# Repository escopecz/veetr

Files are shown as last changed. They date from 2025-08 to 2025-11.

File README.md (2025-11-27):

# Veetr

Veetr provides open source software and hardware for tracking wind speed, direction, speed over ground, GPS tracking, heading, heel and other data in real time during a sail. Great fit for day-sailers or weekend-sailers.

## Features

### 🌊 Real-time Sailing Data
- **SOG** (Speed Over Ground) using GPS
- **AWS** (Apparent Wind Speed) using ultrasonic wind sensor
- **AWA** (Apparent Wind Angle) using ultrasonic wind sensor  
- **TWS** (True Wind Speed) calculated from SOG, AWS, and AWA
- **TWA** (True Wind Angle) calculated from SOG and AWA
- **Heel** (Heeling angle) using 9-axis IMU sensor
- **HDG** (Heading angle to magnetic north) using 9-axis IMU sensor
- **GPS Position** with satellite count and HDOP accuracy

### 📱 Progressive Web App (PWA)
- **Offline Capability** - Works without internet connection after initial load
- **Mobile Installation** - Install as native app on phones and tablets
- **Responsive Design** - Optimized for all screen sizes and orientations
- **Light & Dark Mode** - Perfect for sunny days and night passages
- **Always Up-to-Date** - Automatic updates when internet is available

### 🔄 Firmware & Connectivity
- **OTA Updates** - Over-the-air firmware updates through the web app
- **Multi-Device Support** - Up to 4 devices can connect simultaneously
- **Bluetooth Security** - Discovery mode only when button is pressed (5-minute window)
- **Real-time Data** - 1-second refresh rate for live sailing data
- **RSSI Monitoring** - Signal strength indicator with connection quality

### 🏁 Racing Features
- **Regatta Starting Line** - Pin 2 GPS points and track distance to start line
- **Visual Compass** - Wind direction and heading display with smooth animations
- **Satellite Status** - GPS quality monitoring with visual indicators
- **Connection Management** - Robust BLE connection with automatic reconnection

## Why Veetr?

### 💰 Cost-Effective
- **Open source software** - Free firmware and app to use, install, host yourself and/or modify
- **Open hardware** - PCB Gerber files included for custom manufacturing ([download files](./pcb/))
- **Modular design** - Use standard sensors from AliExpress with pin headers ([full parts list](./docs/HARDWARE.md))
- **3D printed case** - Print yourself or with local maker community
- **Budget-friendly** - Complete electronic components for ~$250 (2025 pricing)

### ⚡ Performance & Reliability
- **Modular architecture** - Easy to repair, upgrade, or replace individual sensors
- **Low power consumption** - 10Ah powerbank provides ~24 hours at 1-second refresh rate
- **No moving parts** - Ultrasonic wind sensor for precision and durability
- **Lightweight** - Wind sensor: 66x64mm, 89 grams
- **Quality sensors** - High-precision components without compromise

### 🔒 Security & Independence
- **Physical Security** - Bluetooth discoverable only with button press (5-minute window)
- **Privacy-First** - All data stays on your device, no cloud dependency
- **USB-C Power** - Works with any standard powerbank or USB-C charger

## Technology Stack

### 🌐 Web Dashboard:
- **React 18** + TypeScript + Vite for modern development
- **Progressive Web App (PWA)** with Service Worker for offline capability
- **Web Bluetooth API** for direct BLE communication
- **Lucide React Icons** for consistent, scalable vector graphics
- **CSS Custom Properties** for theming and responsive design
- **Responsive Layout** optimized for mobile, tablet, and desktop

### 🔧 ESP32 Firmware:
- **Arduino Framework** via PlatformIO for robust development
- **NimBLE Stack** for Bluetooth Low Energy with multi-connection support
- **Multi-Sensor Integration** ([hardware details](./docs/HARDWARE.md)):
  - GPS module (UART) for position and speed
  - BNO080 IMU (I2C) for heading and heel
  - Ultrasonic wind sensor (RS485) for wind speed/direction
- **RSSI Filtering** with moving average for stable signal strength
- **Discovery Mode Security** with button-activated pairing
- **OTA Update Support** for seamless firmware upgrades

### 📡 Communication Protocol:
- **BLE GATT Services** for sensor data streaming
- **JSON Data Format** for structured sensor readings
- **Real-time Updates** at 1Hz refresh rate
- **Multi-device Broadcasting** supporting up to 4 concurrent connections

## 🔧 Hardware Design

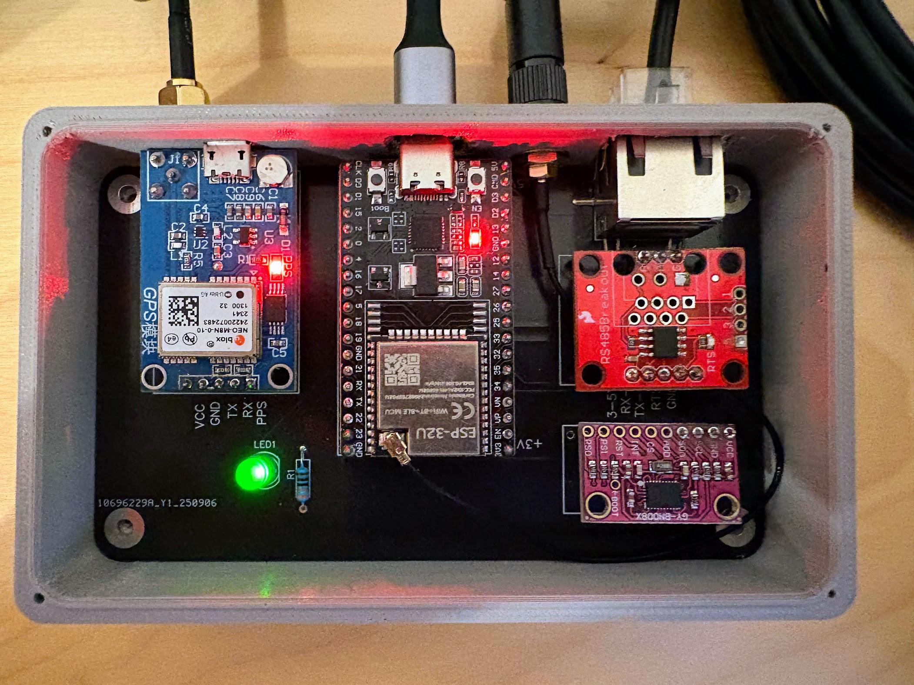
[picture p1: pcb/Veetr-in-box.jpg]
Veetr PCB Assembly


Veetr uses a **modular breakout board design** with standard off-the-shelf sensors for maximum flexibility and repairability.

**📋 Full Details**: [Hardware Guide](./docs/HARDWARE.md) | **🔧 PCB Files**: [Manufacturing Files](./pcb/)

## 🚀 Quick Start

### For Sailors (Using the App):
1. **Visit** [app.veetr.org](https://app.veetr.org) on your mobile device
2. **Install** the app (tap "Add to Home Screen" or "Install" prompt)
3. **Press** the physical button on your Veetr device to enable discovery mode or restart the device
4. **Connect** via the Bluetooth button in the app
5. **Sail** with real-time data - works offline once connected!

### For Developers:
```bash
# Clone and setup web app
git clone https://github.com/escopecz/veetr.git
cd veetr/app
npm install
npm run dev

# Setup firmware development
cd ../firmware
pio run --target upload
```

## Documentation

For detailed information, see the [docs/](./docs/) directory:

- **[Setup Guide](./docs/SETUP.md)** - Step-by-step user setup for sailors
- **[Development Guide](./docs/DEVELOPMENT.md)** - Developer workflow and contribution guide
- **[Hardware Guide](./docs/HARDWARE.md)** - ESP32 wiring and sensor specifications
- **[PCB Files](./pcb/README.md)** - Gerber files and PCB manufacturing information ([download Gerbers](./pcb/gerbers/))
- **[Compliance & Certifications](./docs/COMPLIANCE.md)** - FCC, CE, IC regulatory compliance
- **[Firmware Update Guide](./docs/FIRMWARE_UPDATE.md)** - How to update ESP32 firmware
- **[PlatformIO Guide](./docs/PLATFORMIO.md)** - Firmware development details
- **[Storage Architecture](./docs/STORAGE.md)** - Data storage and persistence
- **[Version Management](./docs/VERSION_MANAGEMENT.md)** - Release and versioning workflow

## License

MIT License - see [LICENSE](./LICENSE) for details.

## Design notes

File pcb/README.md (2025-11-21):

# Veetr PCB Files

This directory contains the PCB design files for the Veetr ESP32 breakout board.

Veetr PCB Assembly

## Modular Design Philosophy

Veetr uses a **modular breakout board design** with standard off-the-shelf sensors for maximum flexibility and repairability.

**📋 Full Details**: [Hardware Guide](../docs/HARDWARE.md)

## Design Files

The complete PCB and schematic design is available on EasyEDA (OSHWLab):

**🔗 [Veetr Breakout Board on EasyEDA](https://oshwlab.com/linhartescope/esp32-breakout-board)**

This project includes:
- Complete schematic design
- PCB layout with component placement
- Bill of Materials (BOM)
- 3D preview of the assembled board

The design can be opened, edited, and customized directly in EasyEDA's web-based editor. You can also fork the project to create your own variations. **Contributions and improvements are welcome!**

## Manufacturing Files

### Gerber Files (`gerbers/`)
Generated on: 2025-09-06

Contains standard Gerber files for PCB fabrication:
- `Gerber_TopLayer.GTL` - Top copper layer
- `Gerber_BottomLayer.GBL` - Bottom copper layer  
- `Gerber_TopSilkscreenLayer.GTO` - Top silkscreen
- `Gerber_BottomSilkscreenLayer.GBO` - Bottom silkscreen
- `Gerber_TopSolderMaskLayer.GTS` - Top solder mask
- `Gerber_BottomSolderMaskLayer.GBS` - Bottom solder mask
- `Gerber_BoardOutlineLayer.GKO` - Board outline
- `Gerber_DocumentLayer.GDL` - Documentation layer
- `Drill_PTH_Through.DRL` - Plated through holes
- `Drill_PTH_Through_Via.DRL` - Via holes
- `Drill_NPTH_Through.DRL` - Non-plated through holes

## PCB Specifications

- **Board Size**: TBD
- **Layers**: 2-layer PCB
- **Thickness**: 1.6mm (standard)
- **Material**: FR4
- **Finish**: HASL (Hot Air Solder Leveling) or ENIG
- **Min Trace Width**: 0.1mm
- **Min Via Size**: 0.2mm

## Manufacturing Notes

See https://docs.easyeda.com/en/PCB/Order-PCB for specific ordering instructions and requirements.

### Recommended PCB Manufacturers
- **JLCPCB** - Cost-effective for prototypes and small runs
- **PCBWay** - Good quality and service
- **OSH Park** - USA-based, high quality
- **AISLER** - Europe-based

## License

This PCB design is released under the same MIT license as the rest of the Veetr project.

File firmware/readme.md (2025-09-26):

# Veetr Sailing Dashboard

A sailing vessel monitoring system built with ESP32, providing real-time data on vessel speed, wind conditions, and tilt angle through a modern web application that connects via Bluetooth Low Energy (BLE).

## 🚨 Architecture Update

**This project has been migrated from WiFi Access Point to BLE (Bluetooth Low Energy) connectivity:**

- **OLD:** ESP32 hosted WiFi Access Point + WebSocket server + web files on SPIFFS
- **NEW:** ESP32 BLE server + externally hosted web app + Web Bluetooth API connection

**Key Changes:**
- Web application is now hosted externally (GitHub Pages, Netlify, etc.) over HTTPS
- ESP32 no longer needs to host web files or run a WiFi Access Point
- Connection is via Bluetooth Low Energy using Web Bluetooth API with NimBLE-Arduino
- Significantly reduced memory usage and improved power efficiency
- Browser support limited to Chrome, Edge, Opera (no Safari/iOS support)
- Standardized JSON API with marine terminology (SOG, AWS, TWS, etc.)
- Robust sensor error handling - system continues to operate even if sensors fail

## Features

- Real-time monitoring of sailing data:
  - Vessel speed over ground (SOG) via GPS with noise filtering
  - Wind speed and angle (AWS/AWA) via ultrasonic sensor
  - Calculated true wind speed and angle (TWS/TWA) using vessel motion
  - Vessel heel/tilt angle via BNO080 IMU sensor (when available)
  - GPS position and satellite information
  - BLE connection strength (RSSI)
- Progressive Web App (PWA) dashboard:
  - Installable on mobile devices
  - Works offline (interface only)
  - Responsive design for all screen sizes
  - Hosted externally (GitHub Pages or any HTTPS hosting)
- Bluetooth Low Energy (BLE) connectivity:
  - Direct connection between web app and ESP32
  - No WiFi network required
  - Low power consumption
  - Secure pairing
  - Multi-client support
- Real-time data updates via BLE notifications (1Hz)
- Data visualization with gauges and charts
- Robust sensor error handling - system continues operating even if sensors fail

## BLE JSON API

The Veetr Sailing Dashboard transmits data via BLE notifications using a standardized JSON format with marine terminology. Data is sent approximately every 1 second to all connected BLE clients.

### BLE Service and Characteristics

- **Service UUID:** `12345678-1234-5678-9abc-def123456789`
- **Characteristic UUID:** `87654321-4321-8765-cba9-fedcba987654`
- **Properties:** Read, Notify
- **Data Format:** JSON string encoded as UTF-8

### JSON Data Structure

```json
{
  "SOG": 4.2,
  "COG": 185.5,
  "lat": 37.7749,
  "lon": -122.4194,
  "satellites": 8,
  "hdop": 1.2,
  "AWS": 12.5,
  "AWA": 45.5,
  "TWS": 10.8,
  "TWA": 52.3,
  "heel": -5.2,
  "HDM": 185.5,
  "accelX": 0.12,
  "accelY": -0.05,
  "accelZ": 9.81,
  "rssi": -65,
  "deviceName": "Luna_Port_Side"
}
```

### Field Definitions

| Field | Type | Unit | Description | Marine Standard |
|---|---|---|---|---|
| `SOG` | float | knots | Speed Over Ground from GPS | ✓ |
| `COG` | float | degrees | Course Over Ground from GPS (0-360°) | ✓ |
| `lat` | float | decimal degrees | GPS Latitude (WGS84) | ✓ |
| `lon` | float | decimal degrees | GPS Longitude (WGS84) | ✓ |
| `satellites` | integer | count | Number of GPS satellites in use | ✓ |
| `hdop` | float | dimensionless | Horizontal Dilution of Precision | ✓ |
| `AWS` | float | knots | Apparent Wind Speed | ✓ |
| `AWA` | float | degrees | Apparent Wind Angle (0-360°) relative to bow | ✓ |
| `TWS` | float | knots | True Wind Speed (calculated) | ✓ |
| `TWA` | float | degrees | True Wind Angle (0-360°) relative to bow | ✓ |
| `heel` | float | degrees | Vessel heel angle (+ = starboard, - = port) | ✓ |
| `HDM` | float | degrees | Heading Magnetic from magnetometer (0-360°) | ✓ |
| `accelX` | float | m/s² | Acceleration along X-axis (fore/aft) | ✓ |
| `accelY` | float | m/s² | Acceleration along Y-axis (port/starboard) | ✓ |
| `accelZ` | float | m/s² | Acceleration along Z-axis (up/down) | ✓ |
| `rssi` | integer | dBm | BLE signal strength (more negative = weaker) | - |
| `deviceName` | string | - | BLE device name for multi-device identification | - |

### Field Behavior

**Always Present:**
- `SOG`, `COG`, `lat`, `lon`, `satellites`, `hdop` - GPS data (0 values if no GPS fix)
- `rssi` - BLE signal strength
- `deviceName` - BLE device name for multi-device identification

**Conditionally Present:**
- `AWS` - Only present if wind sensor is connected and working
- `AWA` - Only present if wind sensor is connected and working
- `TWS` - Only present if wind sensor and GPS are working (calculated from AWS, AWA, SOG)
- `TWA` - Only present if wind sensor and GPS are working (calculated from AWA, SOG)  
- `heel` - Only present if BNO080 IMU sensor is detected and working
- `HDM` - Only present if BNO080 magnetometer is working and has valid data
- `accelX`, `accelY`, `accelZ` - Only present if BNO080 accelerometer is working and has valid data

### GPS Speed Filtering

The system includes intelligent GPS speed filtering that combines GPS track analysis with accelerometer data to accurately distinguish real vessel movement from GPS noise when stationary or docked.

**How it works:**
1. **GPS Track Analysis:** Collects recent GPS positions and analyzes the vessel's track for distance traveled and bearing changes
2. **Accelerometer Movement Detection:** Analyzes acceleration magnitude variations to detect physical movement independent of GPS
3. **Sensor Fusion:** Combines both GPS and accelerometer data for more accurate movement detection
4. **Quality Check:** Only uses GPS data with ≥4 satellites and HDOP ≤ 3.0
5. **Adaptive Thresholds:** Adjusts noise filtering thresholds based on sensor confidence
6. **Hysteresis:** Different thresholds prevent speed "flickering" between 0 and low values

**Key Features:**
- **Dual-Sensor Validation:** Uses both GPS track analysis and accelerometer data when IMU is available
- **Independent Movement Detection:** Accelerometer provides movement confirmation independent of GPS signal quality
- **Adaptive Filtering:** Lower thresholds when both sensors confirm movement, higher when stationary
- **Graceful Degradation:** Falls back to GPS-only filtering when IMU sensor is not available
- **Responsive:** Quickly detects when vessel starts moving after being stationary

**Enhanced Thresholds (with Accelerometer):**
- **High Confidence Movement:** 0.05 knots (both GPS and accelerometer detect movement)
- **Normal Filtering:** 0.08 knots (mixed signals or IMU unavailable)
- **High Confidence Stationary:** 0.12 knots (both sensors confirm stationary state)
- **Start Moving Hysteresis:** +0.1 knots above respective threshold

**Accelerometer Movement Detection:**
- **Acceleration Variance:** Detects changes in acceleration magnitude indicating movement
- **Magnitude Analysis:** Monitors total acceleration range and standard deviation
- **Validation:** Ensures accelerometer readings are reasonable (gravity present: 8-12 m/s²)
- **Noise Immunity:** Filters false positives from sensor noise or vibrations

**Why This Approach:**
This dual-sensor approach significantly improves accuracy over GPS-only filtering:
- **Eliminates False Positives:** GPS noise won't register as movement without accelerometer confirmation
- **Reduces False Negatives:** Real movement detected by accelerometer even with poor GPS signal
- **Better Sensitivity:** Can detect very slow movement (below GPS noise floor) when accelerometer confirms motion
- **Marine Environment Optimized:** Accounts for wave motion, anchoring, and low-speed maneuvering scenarios

### Error Handling

The system is designed to be robust against sensor failures:

- **Missing GPS:** System continues to operate, GPS fields show default values
- **Missing Wind Sensor:** Wind fields (`AWS`, `AWA`, `TWS`, `TWA`) are omitted from JSON
- **Missing IMU Sensor:** Heel field is omitted from JSON
- **Sensor Failures:** Individual sensor failures don't affect other sensors or BLE transmission
- **BLE Reliability:** JSON is transmitted every 1 second regardless of sensor status

### BLE Commands

The Veetr Sailing Dashboard supports bidirectional communication via a dedicated command characteristic. This allows web applications to configure device settings and trigger actions remotely.

#### Command Characteristic

- **Characteristic UUID:** `11111111-2222-3333-4444-555555555555`
- **Properties:** Write
- **Data Format:** JSON string encoded as UTF-8

#### Available Commands

**1. Reset Heel Angle (Calibration)**
```json
{
  "action": "resetHeelAngle"
}
```
Calibrates the heel angle sensor by setting the current tilt as the new zero point. Useful for adjusting when the boat is level.

**2. Set Device Name**
```json
{
  "action": "setDeviceName",
  "deviceName": "Luna_Port_Side"
}
```
Sets the BLE device name used for Bluetooth discovery. This is essential for distinguishing between multiple ESP32 devices. Limited to 1-20 characters, alphanumeric, underscore, hyphen, and space only.

**3. Regatta Line Markers (Future)**
```json
{
  "action": "regattaSetPort"
}
```
```json
{
  "action": "regattaSetStarboard"
}
```
Placeholder commands for future regatta timing functionality.

#### Multi-Device Management

The device name feature is particularly useful for sailing applications with multiple sensors:

- **Fleet Management:** "Veetr_01", "Veetr_02", "Veetr_03"
- **Multi-Hull Boats:** "Veetr_Port", "Veetr_Starboard"
- **Multiple Locations:** "Veetr_Mast", "Veetr_Cockpit"
- **Development/Testing:** "Veetr_Dev", "Veetr_Prod"

When you change the device name, the ESP32 immediately restarts its BLE advertising with the new name, making it instantly discoverable under the new identifier.

### Example Client Code (JavaScript)

```javascript
// Connect to Veetr Sailing BLE device
const device = await navigator.bluetooth.requestDevice({
  filters: [{ name: 'Veetr_Sailing' }],
  optionalServices: ['12345678-1234-5678-9abc-def123456789']
});

const server = await device.gatt.connect();
const service = await server.getPrimaryService('12345678-1234-5678-9abc-def123456789');

// Get sensor data characteristic for reading
const sensorCharacteristic = await service.getCharacteristic('87654321-4321-8765-cba9-fedcba987654');

// Get command characteristic for writing
const commandCharacteristic = await service.getCharacteristic('11111111-2222-3333-4444-555555555555');

// Listen for sensor data notifications
sensorCharacteristic.addEventListener('characteristicvaluechanged', (event) => {
  const value = event.target.value;
  const jsonString = new TextDecoder().decode(value);
  const data = JSON.parse(jsonString);
  
  console.log('Speed:', data.SOG, 'knots');
  console.log('Wind Speed:', data.AWS, 'knots');
  console.log('Heel:', data.heel, 'degrees');
  console.log('Device:', data.deviceName);
  
  // New BNO080 sensor data (if available)
  if (data.HDM !== undefined) {
    console.log('Magnetic Heading:', data.HDM, 'degrees');
  }
  
  if (data.accelX !== undefined) {
    console.log('Acceleration:', {
      x: data.accelX,
      y: data.accelY, 
      z: data.accelZ
    }, 'm/s²');
  }
});

await sensorCharacteristic.startNotifications();

// Send commands to the device
async function setDeviceName(newName) {
  const command = {
    action: "setDeviceName",
    deviceName: newName
  };
  
  const encoder = new TextEncoder();
  const data = encoder.encode(JSON.stringify(command));
  await commandCharacteristic.writeValue(data);
  
  console.log(`Device name set to: ${newName}`);
}

async function resetHeelAngle() {
  const command = { action: "resetHeelAngle" };
  
  const encoder = new TextEncoder();
  const data = encoder.encode(JSON.stringify(command));
  await commandCharacteristic.writeValue(data);
  
  console.log('Heel angle reset (calibrated)');
}

// Example usage
await setDeviceName('Luna_Port_Side');
await resetHeelAngle();
```

## Hardware Components

- ESP32 DevKitC WROOM-32U (main controller with external antenna)
- NEO-7M GPS Module with external antenna
- Ultrasonic Wind Speed and Direction Sensor (RS485) - **Auto-detects sensor format**
- GY-BNO080 9-Axis IMU Sensor (I2C)
- RS485 to UART Converter Module

### Wind Sensor Compatibility

The system automatically detects and supports two different ultrasonic wind sensor formats:

- **IEEE754 Format**: 9600 baud, 8E1, registers 0x0001, IEEE 754 float encoding
- **Integer Format**: 4800 baud, 8N1, registers 0x0000, integer×100 encoding

Auto-detection occurs at startup by attempting communication with each format and validating the response data. Once detected, the system locks to the working format for optimal performance.

## Getting Started

### Development Setup

For complete development environment setup, daily workflow, and contribution guidelines, see the **[Development Guide](../docs/DEVELOPMENT.md)**.

This firmware documentation focuses on ESP32-specific implementation details and BLE protocol specifications.

#### Hardware Setup

1. **Wire the Sensors to ESP32**
For detailed hardware wiring and sensor specifications, see the **[Hardware Guide](../docs/HARDWARE.md)**.

1. **Wire the Sensors to ESP32**
   - **GPS Module**: UART connection (GPIO16/17)
   - **BNO080 IMU**: I2C connection (GPIO21/22)  
   - **Wind Sensor**: RS485 connection (GPIO32/33/14)

2. **Connect ESP32 to Computer**
   - Use USB cable for programming and power during development
   - For deployment: 5V power bank (portable) or boat's 12V supply with voltage regulator

#### Software Installation

For complete software setup, see the **[Development Guide](../docs/DEVELOPMENT.md)**.

1. **Clone this repository**
   ```bash
   git clone https://github.com/yourusername/luna.git
   cd luna
   ```
   
   Alternatively, download the ZIP file from GitHub and extract it.

2. **Open the project in VS Code with PlatformIO**
   - Launch VS Code
   - Go to Extensions (Ctrl+Shift+X or Cmd+Shift+X)
   - Search for and install "PlatformIO IDE"
   - Restart VS Code when prompted
   - Open the Luna project folder (File > Open Folder)
   - Wait for PlatformIO to initialize the project (this may take a few minutes)

3. **Install required libraries**
   PlatformIO should automatically install the required libraries based on the `platformio.ini` file. If not, you can install them manually:
   
   - Through PlatformIO Home:
     - Click on the PlatformIO icon in the sidebar
     - Go to "Libraries" and search for each library:
       - ArduinoJson
       - SparkFun BNO080 Cortex Based IMU
       - TinyGPS++
       - ModbusMaster
     - Click "Add to Project" and select your project
   
   - Or through the CLI:
     ```bash
     pio pkg install --library "bblanchon/ArduinoJson"
     pio pkg install --library "sparkfun/SparkFun BNO080 Cortex Based IMU"
     pio pkg install --library "mikalhart/TinyGPSPlus"
     pio pkg install --library "4-20ma/ModbusMaster"
     ```

For build, upload, and testing procedures, see the **[Development Guide](../docs/DEVELOPMENT.md)**.

### Connecting to the Dashboard

#### Web Application Access

The Veetr Sailing Dashboard web application is hosted externally (not on the ESP32) to provide better performance and reliability. You can access it at:

**Live Dashboard:** [https://yourusername.github.io/luna-dashboard](https://yourusername.github.io/luna-dashboard)

*Note: Replace the URL above with your actual hosted dashboard URL*

#### Connecting via Bluetooth Low Energy (BLE)

1. **Power on the ESP32**
   - If using USB: Connect to a computer or power bank
   - If using external power: Connect to the boat's power supply

2. **Wait for system initialization**
   - The ESP32 needs about 10-15 seconds to boot up and start the BLE server
   - The ESP32 will advertise as "Luna_Sailing" and be discoverable by BLE devices

3. **Access the web dashboard**
   - Open a BLE-compatible browser (Chrome, Edge, or Opera on desktop/Android)
   - Navigate to the dashboard URL (hosted externally)
   - The dashboard must be served over HTTPS for Web Bluetooth API to work

4. **Connect to the ESP32**
   - Click the "Connect to Luna Sailing" button in the dashboard
   - Your browser will show a device selection dialog
   - Select "Luna_Sailing" from the list of available devices
   - Click "Pair" or "Connect"
   - The connection status will change to "Connected via BLE"

5. **Verify the connection**
   - Once connected, you should see real-time data updating in the dashboard
   - Check that the data is updating (approximately once per second)
   - Satellite count should be visible if GPS is connected
   - Sensor values should respond to actual changes in movement, wind, etc.

#### Browser Compatibility

**Supported Browsers with Web Bluetooth API:**
- **Chrome** (Desktop: Windows, macOS, Linux; Mobile: Android)
- **Edge** (Desktop: Windows, macOS; Mobile: Android)
- **Opera** (Desktop: Windows, macOS, Linux; Mobile: Android)

**Not Supported:**
- Safari (iOS/macOS) - Does not support Web Bluetooth API
- Firefox - Limited or no Web Bluetooth support
- Most iOS browsers - iOS restricts Web Bluetooth API

**Recommended Setup:**
- Android device with Chrome browser
- Windows/macOS/Linux desktop with Chrome or Edge
- Ensure the dashboard is served over HTTPS

#### Troubleshooting Connection Issues

- **Can't find the Luna_Sailing BLE device**
  - Make sure the ESP32 is powered on and fully booted (wait 15-20 seconds)
  - Try restarting the ESP32 by pressing the reset button
  - Move closer to the ESP32 - BLE range is typically 10-30 meters in open space
  - Ensure you're using a supported browser (Chrome, Edge, or Opera)
  - Check that Bluetooth is enabled on your device

- **Browser shows "Bluetooth not supported" error**
  - Make sure you're using Chrome, Edge, or Opera (not Safari or Firefox)
  - Ensure the dashboard is served over HTTPS (required for Web Bluetooth API)
  - Try updating your browser to the latest version
  - On Android, ensure location services are enabled (required for BLE scanning)

- **Dashboard loads but BLE connection fails**
  - Check that your device's Bluetooth is turned on
  - Try clearing your browser cache and cookies
  - Restart your browser completely
  - Try connecting from a different device
  - Check the browser console (F12) for error messages

- **Connected but no data appears**
  - Check the BLE connection status indicator in the dashboard
  - Refresh the page and try reconnecting
  - If using real sensors, verify they are properly connected to the ESP32
  - Check the ESP32 serial monitor output for any error messages
  - Try restarting the ESP32

- **iOS/Safari compatibility issues**
  - Unfortunately, iOS Safari does not support Web Bluetooth API
  - Use an Android device or desktop browser instead
  - Consider using a third-party iOS browser that might support Web Bluetooth (limited options)

- **Data updates are slow or intermittent**
  - This may be due to BLE connection quality or interference
  - Move closer to the ESP32
  - Remove sources of 2.4GHz interference (WiFi, microwaves, etc.)
  - Try restarting both the ESP32 and reconnecting from the browser

### Installing as a PWA

The Luna Sailing Dashboard is designed as a Progressive Web App (PWA), which means you can install it on your device for easier access and a more app-like experience. Once installed, you can launch it directly from your home screen without opening a browser and navigating to the URL.

**Important:** The PWA must be served over HTTPS to enable installation and Web Bluetooth API functionality.

#### On iPhone/iPad (Safari)

**Note:** While you can install the PWA on iOS, Web Bluetooth is not supported in Safari, so you'll need to use an Android device or desktop browser for BLE connectivity.

1. Open the dashboard URL in Safari (the externally hosted HTTPS version)
2. Tap the Share button (rectangle with an arrow pointing up) at the bottom of the screen
3. Scroll down and tap "Add to Home Screen"
4. You can rename the app if you wish
5. Tap "Add" in the top-right corner
6. The Luna app icon will appear on your home screen
7. Tap the icon to launch the app in full-screen mode

#### On Android (Chrome)

1. Open the dashboard in Chrome (navigate to your hosted dashboard URL)
2. Tap the three-dot menu button in the top-right corner
3. Select "Add to Home screen" or "Install app" (the wording may vary)
4. If prompted, confirm by tapping "Add" or "Install"
5. The Luna app icon will appear on your home screen
6. Tap the icon to launch the app in full-screen mode

#### On Windows (Chrome/Edge)

1. Open the dashboard in Chrome or Edge (navigate to your hosted dashboard URL)
2. Look for the install icon in the address bar (a computer with a down arrow) or the three-dot menu
3. Click "Install Luna Sailing" or "Install app"
4. Confirm by clicking "Install" in the popup
5. The app will install and can be launched from the Start menu or desktop
6. You can also pin it to the taskbar for quick access

#### On macOS (Chrome)

1. Open the dashboard in Chrome (navigate to your hosted dashboard URL)
2. Click the three-dot menu in the top-right corner
3. Select "Install Luna Sailing..." or "Create shortcut..."
4. Choose whether to open as a window or tab
5. Click "Install" or "Create"
6. The app will be added to your Applications folder and can be launched from there

#### Benefits of Installing as a PWA

- **Easier Access**: Launch directly from your home screen without typing the URL
- **Full-Screen Experience**: No browser interface elements taking up space
- **Offline Interface**: The basic dashboard UI remains accessible even without connection (though live data requires BLE connection)
- **Automatic Reconnection**: The app will attempt to reconnect to the ESP32 when BLE connection is available
- **Better Performance**: Installed PWAs often have better performance than browser tabs

#### Troubleshooting PWA Installation

- **Install option not appearing**:
  - Make sure you've fully loaded the dashboard page
  - Try refreshing the page
  - Some browsers may require you to visit the site more than once before offering installation
  - Ensure the site is served over HTTPS
  
- **App not working after installation**:
  - Make sure the ESP32 is powered on and BLE is advertising
  - Try connecting to the ESP32 via BLE from the installed app
  - Check that Bluetooth is enabled on your device
  
- **App showing offline mode**:
  - This is normal if you're not connected to the ESP32 via BLE
  - The app interface remains available, but live data requires BLE connection
  - Connect to the ESP32 via BLE to start receiving data

### BLE Connection and Pairing

The Luna Sailing Dashboard uses Bluetooth Low Energy (BLE) for communication between the ESP32 and client devices. The system is designed to be robust and supports multiple simultaneous connections.

#### BLE Service Information

- **Device Name:** `Luna_Sailing`
- **Service UUID:** `12345678-1234-5678-9abc-def123456789`
- **Characteristic UUID:** `87654321-4321-8765-cba9-fedcba987654`
- **Data Rate:** ~1 Hz (every 1000ms)
- **Data Format:** JSON string with marine terminology

#### Initial Connection Process

1. **Power on the ESP32**
   - Connect to power source (USB or external power)
   - Wait 10-15 seconds for full system initialization
   - The ESP32 will start advertising as "Luna_Sailing"

2. **Activate Discovery Mode**
   - Press and hold the BOOT button (GPIO0) for 1+ seconds
   - The built-in LED (GPIO2) will turn on to indicate discovery mode is active
   - Device becomes discoverable to nearby BLE clients for 5 minutes
   - Range: typically 10-30 meters in open space

3. **Connect from Client Device**
   - Use a BLE-compatible browser or application
   - Search for "Luna_Sailing" in available BLE devices
   - Select device and confirm pairing
   - **Note**: Discovery mode expires after 5 minutes for security
   - Connection establishment takes 2-5 seconds

#### Sensor Initialization Status

The system performs sensor detection during startup:

- **GPS Module:** Always initialized (may take 30-90 seconds for first satellite fix)
- **Wind Sensor:** Automatically detected via RS485 communication
- **IMU Sensor:** Detected via I2C bus scan at startup
- **Missing Sensors:** System continues operation with available sensors only

#### Data Transmission

Once connected, the ESP32 automatically sends JSON data every 1 second:

- **Reliable Timing:** 1Hz transmission regardless of sensor status
- **Error Resilience:** Failed sensors don't interrupt data flow
- **Multi-Client:** Supports multiple simultaneous BLE connections
- **Low Latency:** Minimal delay between sensor reading and transmission

#### BLE Connection Management

**Automatic Reconnection:**
- Client applications should implement automatic reconnection
- ESP32 continues advertising after disconnections
- Previous pairing information is remembered

**Connection Stability:**
- Move closer to ESP32 if connection is unstable
- Avoid obstacles and interference sources
- Battery level affects BLE transmission power

**Multi-Device Support:**
- Multiple phones/tablets can connect simultaneously
- Each client receives independent data stream
- No limit on number of concurrent connections (within BLE stack limits)

#### BLE Discovery Security Mode

For enhanced security when deployed on boats, the ESP32 implements a button-activated discovery mode:

**Default Behavior:**
- BLE advertising is automatically disabled after 5 minutes of operation
- Device becomes "invisible" to BLE scanners for security
- Ideal for unattended deployment on boats in marinas or at anchor

**Manual Discovery Activation:**
- Press and hold the BOOT button (GPIO0) for 1+ seconds
- Built-in LED (GPIO2) turns on to confirm discovery mode is active
- BLE advertising enabled for exactly 5 minutes
- Press BOOT button again to deactivate early if needed

**Security Benefits:**
- Prevents unauthorized BLE scanning when device is unattended
- Perfect for marine environments where device may be left alone for hours/days
- Only advertises when intentionally activated by user
- Visual LED confirmation prevents accidental activation

### BLE Troubleshooting

#### Common BLE Connection Issues

- **Can't find the Luna_Sailing BLE device**
  - **First**: Press and hold the BOOT button (GPIO0) for 1+ seconds to activate discovery mode
  - Verify the built-in LED (GPIO2) turns on (discovery mode active)
  - Make sure the ESP32 is powered on and fully booted (wait 15-20 seconds)
  - Try restarting the ESP32 by pressing the reset button
  - Move closer to the ESP32 - BLE range is typically 10-30 meters in open space
  - Ensure you're using a supported browser (Chrome, Edge, or Opera)
  - Check that Bluetooth is enabled on your device
  - **Remember**: Discovery mode expires after 5 minutes - press BOOT button again if needed

- **Browser shows "Bluetooth not supported" error**
  - Make sure you're using Chrome, Edge, or Opera (not Safari or Firefox)
  - Ensure the dashboard is served over HTTPS (required for Web Bluetooth API)
  - Try updating your browser to the latest version
  - On Android, ensure location services are enabled (required for BLE scanning)

- **Dashboard loads but BLE connection fails**
  - Check that your device's Bluetooth is turned on
  - Try clearing your browser cache and cookies
  - Restart your browser completely
  - Try connecting from a different device
  - Check the browser console (F12) for error messages

- **Connected but no data appears**
  - Check the BLE connection status indicator in the dashboard
  - Refresh the page and try reconnecting
  - If using real sensors, verify they are properly connected to the ESP32
  - Check the ESP32 serial monitor output for any error messages
  - Try restarting the ESP32

- **iOS/Safari compatibility issues**
  - Unfortunately, iOS Safari does not support Web Bluetooth API
  - Use an Android device or desktop browser instead
  - Consider using a third-party iOS browser that might support Web Bluetooth (limited options)

- **Data updates are slow or intermittent**
  - This may be due to BLE connection quality or interference
  - Move closer to the ESP32
  - Remove sources of 2.4GHz interference (WiFi, microwaves, etc.)
  - Try restarting both the ESP32 and reconnecting from the browser

#### Sensor-Specific Troubleshooting

- **GPS shows no satellites or zero speed**
  - Ensure GPS antenna has clear view of sky
  - Move away from buildings, trees, or other obstructions
  - GPS requires 30-90 seconds for initial satellite acquisition
  - Check that GPS module is properly connected to pins 16/17

- **Wind data not appearing in JSON**
  - Verify wind sensor is connected to RS485 converter
  - Check RS485 converter connections to ESP32 pins 32/33
  - Ensure wind sensor has proper power supply (5-12V, 5V power bank works)
  - Check serial console for auto-detection messages during startup
  - System automatically tries both IEEE754 and integer formats
  - Wind sensor data only appears in JSON when sensor is detected and working
  - If auto-detection fails, verify Modbus address is set to 1 on the sensor

- **Heel angle not appearing in JSON**
  - Verify BNO080 IMU sensor is connected to I2C pins 21/22
  - Check that IMU sensor has proper power supply (3.3V)
  - Heel data only appears in JSON when IMU sensor is detected at startup
  - If IMU sensor fails after startup, heel data will stop appearing

- **JSON missing expected fields**
  - This is normal behavior - fields are omitted if sensors are not available
  - Only GPS fields (SOG, COG, lat, lon, satellites, hdop) and RSSI are always present
  - Wind fields (AWS, AWD) only appear when wind sensor is connected
  - Heel field only appears when IMU sensor is detected and working

## Development

### Sensor Calibration and Configuration

#### GPS Module (NEO-7M)

1. **Initial Setup**
   - The GPS module requires a clear view of the sky to acquire a satellite fix
   - For best results, position the antenna horizontally with an unobstructed view
   - Initial satellite acquisition can take 30-90 seconds in ideal conditions, or longer in poor conditions
   - The blue LED on the GPS module will blink when it has a fix

2. **Configuration Options**
   - The GPS update rate is set to 1Hz by default (in `src/sensors/gps.cpp`)
   - To modify GPS settings, you can adjust the following parameters:
     ```cpp
     // Change update rate (default is 1Hz)
     const int GPS_UPDATE_RATE = 1000; // in milliseconds
     
     // Change serial baud rate if needed
     const int GPS_BAUD_RATE = 9600;
     ```

#### IMU Sensor (BNO080)

1. **Calibration Process**
   - The BNO080 IMU sensor has built-in calibration algorithms that continuously calibrate the sensor
   - For manual calibration reset:
     1. Position the ESP32 and IMU sensor in a perfectly level position
     2. Navigate to the dashboard's Settings tab
     3. Click "Calibrate IMU Sensor"
     4. Wait for the calibration to complete (about 5 seconds)
     5. The calibration values are stored in the ESP32's flash memory

2. **Sensor Fusion Features**
   - The BNO080 provides automatic sensor fusion combining accelerometer, gyroscope, and magnetometer data
   - Built-in drift compensation and noise filtering
   - Quaternion output for precise orientation tracking
   - No manual calibration typically required for basic tilt measurements

3. **Mounting Considerations**
   - Mount the IMU sensor with the X-axis aligned with the fore-aft axis of the boat
   - The Y-axis should be aligned with the port-starboard axis
   - The Z-axis should be pointing upward
   - The BNO080's sensor fusion algorithms can compensate for minor mounting misalignments
   - For best results, mount rigidly to minimize vibration effects

#### Wind Sensor

1. **Auto-Detection**
   - The system automatically detects your wind sensor format at startup
   - Supports both IEEE754 float (9600,8E1) and integer (4800,8N1) formats
   - No manual configuration required - the system tests both formats and locks to the working one
   - Detection status is shown in the serial console during startup

2. **Supported Formats**
   - **IEEE754 Format**: 9600 baud, 8E1, registers 0x0001, speed as IEEE 754 float
   - **Integer Format**: 4800 baud, 8N1, registers 0x0000, speed as integer×100

3. **Calibration**
   - The ultrasonic wind sensor should be calibrated according to manufacturer instructions
   - Most sensors require physical calibration at installation (aligning to boat's centerline)
   - No software calibration is typically needed as readings are absolute
     const int WIND_UPDATE_RATE = 1000;    // Update rate in milliseconds
     const int WIND_SENSOR_BAUDRATE = 9600; // Baud rate for RS485 communication
     ```

3. **Mounting Position**
   - Mount the wind sensor at the highest practical point for accurate readings
   - Ensure it's away from obstructions that could cause wind shadow or turbulence
   - For powerboats or when running with engines, be aware that exhaust gases can affect readings

### Project Structure

- `/src`: Main C++ code for ESP32 (BLE server using NimBLE-Arduino and sensor management)
- `/data/www`: Web dashboard files (legacy - now hosted externally)
  - `/css`: Stylesheets
  - `/js`: JavaScript files (including BLE connection logic)
  - `/images`: Icons and graphics
- `/include`: Header files and sensor documentation
- `/lib`: Libraries
- `/platformio.ini`: Build configuration with NimBLE-Arduino library

**Note:** The `/data/www` folder contains the web application files for reference and local development, but in the new BLE architecture, these files should be hosted externally (e.g., GitHub Pages) rather than uploaded to the ESP32's filesystem.

**Key Code Files:**
- `src/main.cpp`: Main ESP32 firmware with BLE server, sensor management, and JSON API
- Uses NimBLE-Arduino for efficient BLE communication
- Implements robust error handling for missing or failed sensors
- Provides standardized marine JSON API over BLE notifications

For build, upload, and development procedures, see the **[Development Guide](../docs/DEVELOPMENT.md)** and **[PlatformIO Guide](../docs/PLATFORMIO.md)**.

For build, upload, and development procedures, see the **[Development Guide](../docs/DEVELOPMENT.md)** and **[PlatformIO Guide](../docs/PLATFORMIO.md)**.

## License

This project is licensed under the MIT License - see the LICENSE file for details.

## Power Management and Battery Operation

The Luna Sailing Dashboard is designed to operate efficiently on battery power, making it suitable for extended use on sailing vessels without constant shore power. The migration to BLE significantly improves power efficiency over the previous WiFi-based design.

### Power Requirements

- **ESP32 Power Consumption (BLE Mode)**:
  - Normal operation (BLE active): ~60-80mA @ 5V (~0.3-0.4W)
  - Deep sleep mode: ~10μA @ 5V (negligible)
  - **BLE Advantage**: Uses ~50% less power than WiFi Access Point mode
  - **NimBLE Efficiency**: NimBLE-Arduino library provides additional power savings
  
- **Sensor Power Requirements**:
  - GPS Module: ~50mA @ 3.3V
  - BNO080 IMU Sensor: ~0.5mA @ 3.3V (when present)
  - Wind Sensor: Varies by model, typically 100-300mA @ 5-12V
  
- **Total System**:
  - Typical consumption: ~140-180mA @ 5V (0.7-0.9W)
  - With 10Ah power bank: approximately 40-50 hours of operation
  - **Significant improvement** over WiFi-based design

### Battery Connection Options

1. **Direct USB Power Bank**:
   - Simplest solution for mobile/temporary installations
   - Connect standard USB power bank to ESP32's micro-USB port
   - No additional components required
   - Recommended capacity: 10Ah or higher for multi-day operation

2. **Boat 12V System Integration**:
   - Requires 12V to 5V voltage regulator/converter
   - Recommended: Buck converter with at least 1A output capacity
   - Connect output to ESP32's 5V and GND pins (not via USB)
   - Add power switch and fuse for safety
   - Enables permanent installation with boat's electrical system

3. **Solar Power Option**:
   - Small 5W-10W solar panel
   - Solar charge controller (MPPT preferred)
   - 3.7V LiPo battery (3000mAh or larger recommended)
   - LiPo to 5V boost converter
   - Can provide continuous operation in sunny conditions
   - Ideal for remote installations or extended cruising

### Power-Saving Features

1. **BLE Power Efficiency**:
   - NimBLE-Arduino library optimized for low power consumption
   - Automatic connection interval management
   - Efficient multi-client support without power penalty
   - No WiFi radio power consumption

2. **Sensor Error Handling**:
   - Failed sensors don't cause power-consuming retry loops
   - I2C and RS485 timeouts prevent blocking operations
   - Graceful degradation maintains power efficiency

3. **Optimized Update Intervals**:
   - 1Hz data transmission balances responsiveness with power efficiency
   - GPS and sensor polling optimized for power consumption
   - No continuous polling of failed sensors

### Power Monitoring

The system provides power-related information:

- **BLE RSSI**: Indicates signal strength, which correlates with power consumption
- **Sensor Status**: Missing sensors automatically reduce power consumption
- **Connection Status**: Monitor multiple BLE connections for power impact

### Battery Life Estimates

**With 10Ah USB Power Bank:**
- GPS + BLE only: ~50-60 hours
- GPS + BLE + IMU Sensor: ~45-55 hours  
- GPS + BLE + Wind Sensor: ~30-40 hours
- All sensors active: ~25-35 hours

**With 12V Boat System:**
- Continuous operation with proper sizing
- Recommended: 5A circuit breaker
- Typical load: 0.5-1A @ 12V including sensors

### Power-Saving Tips

1. **Optimize Connection Intervals**:
   - Modern BLE clients can negotiate efficient connection intervals
   - Lower connection intervals increase power consumption
   - 1Hz data rate is optimal balance of responsiveness and efficiency

2. **Sensor Configuration**:
   - Disable unused sensors to save power
   - Wind sensor is typically the highest power consumer
   - GPS power consumption is relatively constant

3. **Installation Considerations**:
   - Good BLE signal strength reduces power consumption
   - Avoid obstacles between ESP32 and client devices
   - Consider ESP32 placement for optimal antenna performance

## Acknowledgments

- [ESP32 Arduino Core](https://github.com/espressif/arduino-esp32)
- [ESPAsyncWebServer](https://github.com/me-no-dev/ESPAsyncWebServer)
- [Chart.js](https://www.chartjs.org/)
- [ArduinoJson](https://arduinojson.org/)

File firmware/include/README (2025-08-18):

This directory contains project header files and documentation for hardware components.

Veetr - Hardware Documentation:

- RS485_Breakout_v10.pdf: Documentation for RS485 to UART converter module
- Ultrasonic Wind Speed and Direction Sensor(RS485).doc.pdf: Wind sensor documentation
- adxl345-ep.pdf: Accelerometer documentation (legacy - now using BNO080)

Wind Sensor Notes:
The system automatically detects between two common ultrasonic wind sensor formats:
- IEEE754 Format: 9600 baud, 8E1, registers 0x0001, IEEE 754 float encoding
- Integer Format: 4800 baud, 8N1, registers 0x0000, integer×100 encoding

No manual configuration required - detection happens at startup.

A header file is a file containing C declarations and macro definitions
to be shared between several project source files. You request the use of a
header file in your project source file (C, C++, etc) located in `src` folder
by including it, with the C preprocessing directive `#include'.

```src/main.c

#include "header.h"

int main (void)
{
 ...
}
```

Including a header file produces the same results as copying the header file
into each source file that needs it. Such copying would be time-consuming
and error-prone. With a header file, the related declarations appear
in only one place. If they need to be changed, they can be changed in one
place, and programs that include the header file will automatically use the
new version when next recompiled. The header file eliminates the labor of
finding and changing all the copies as well as the risk that a failure to
find one copy will result in inconsistencies within a program.

In C, the convention is to give header files names that end with `.h'.

Read more about using header files in official GCC documentation:

* Include Syntax
* Include Operation
* Once-Only Headers
* Computed Includes

https://gcc.gnu.org/onlinedocs/cpp/Header-Files.html

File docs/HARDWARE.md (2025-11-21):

# Veetr - Hardware Documentation

Technical documentation for the ESP32-based sailing sensor hardware and dashboard integration.

## Hardware Overview

The Veetr uses an ESP32 microcontroller with multiple sensors to provide comprehensive sailing data via Bluetooth Low Energy (BLE) to a web-based dashboard.

Veetr PCB Assembly

## Modular Design Philosophy

Veetr employs a **modular breakout board architecture** for maximum flexibility and maintainability:

### 🔧 Design Benefits
- **Standard Components**: All sensors are off-the-shelf modules with pin headers
- **Easy Replacement**: Swap faulty sensors without system redesign  
- **Future-Proof**: Upgrade individual sensors as technology improves
- **Cost-Effective**: No custom sensor manufacturing required
- **Repair-Friendly**: Replace only broken components
- **Expandable**: Add new sensors by updating firmware and PCB layout ([PCB files available](../pcb/))

### 🔌 Connection Method
- **Pin Headers**: Standard 2.54mm pitch pin headers for all connections
- **Breadboard Compatible**: Prototype on breadboard before PCB assembly ([Gerber files for manufacturing](../pcb/gerbers/))
- **Modular Cables**: Use DuPont cables for temporary connections

## Note on Affiliate Links
Some of the parts listed below use affiliate links. If you choose to purchase through these, a small portion comes back to support the project’s ongoing development. This doesn’t change the price you pay. If you’d rather not use affiliate links, feel free to search for the part numbers directly (a quick Google search will usually turn them up).

## Hardware Components

### 🔧 Main Controller:

#### ESP32 DevKitC WROOM-32U Development Board
ESP32 DevKitC WROOM-32U Development Board (https://s.click.aliexpress.com/e/_onsyWtH)
- **Purchase Link:** https://s.click.aliexpress.com/e/_onsyWtH
- **Product Name:** ESP32 DevKitC WIFI+Bluetooth Development Board WROOM & WIFI Module with 2.4G Antenna Optional ESP32-WROOM-32U Development Board
- **Board Type:** ESP32 DevKitC WROOM-32U
- **Module:** ESP32-WROOM-32U (with external antenna connector)
- **Processor:** Tensilica Xtensa Dual-Core 32-bit LX6 microprocessor
- **Clock Speed:** Up to 240MHz (adjustable for power management)
- **Operating Voltage:** 3.3V (with onboard voltage regulator for 5V input)
- **Flash Memory:** 4MB (for firmware and file storage)
- **SRAM:** 520KB (for runtime variables and program execution)
- **Connectivity:**
  - Wi-Fi: 802.11 b/g/n (2.4 GHz) with external antenna connector - not used in this marine application
  - Bluetooth: v4.2 BR/EDR + BLE (using BLE for low power marine communication)
  - **External Antenna:** U.FL/IPEX connector for 2.4G antenna (recommended for marine use)
- **GPIO Pins:** 36 total pins (34 usable as GPIO)
- **ADC:** 12-bit resolution, 18 channels (for analog sensor reading)
- **DAC:** 8-bit resolution, 2 channels
- **Communication Interfaces:**
  - SPI: 4 interfaces (for high-speed sensor communication)
  - I2C: 2 interfaces (used for IMU sensor)
  - I2S: 2 interfaces (for audio applications)
  - UART: 3 interfaces (used for GPS and RS485 communication)
  - CAN: 1 interface
- **PWM:** 16 channels (software configurable)
- **Capacitive Touch:** 10 GPIO pins support touch sensing
- **Form Factor:** Breadboard-friendly with dual-row pin layout
- **USB Interface:** USB-C for programming and power
- **Power Management:** Onboard AMS1117 3.3V regulator
- **Reset/Boot:** Physical buttons for reset and flash mode
- **LED Indicators:** Built-in power and programmable LEDs
- **Marine Suitability:** Robust design suitable for marine electronics projects
- **Antenna Options:** Can be ordered with or without external 2.4G antenna (external antenna recommended for marine applications to improve BLE range and reliability)

#### ESP32 Pinout Reference
```
                    ESP32 DevKitC WROOM-32U
                   +--------------------+
              3V3 -|3V3              GND|- GND
              EN  -|EN               IO23|- IO23/VSPI_MOSI
              VP  -|IO36/VP         IO22|- IO22/I2C_SCL
              VN  -|IO39/VN         IO1 |- IO1/TX0
              IO34-|IO34            IO3 |- IO3/RX0
              IO35-|IO35            IO21|- IO21/I2C_SDA
              IO32-|IO32            GND |- GND
              IO33-|IO33            IO19|- IO19/VSPI_MISO
              IO25-|IO25            IO18|- IO18/VSPI_CLK
              IO26-|IO26            IO5 |- IO5/VSPI_CS
              IO27-|IO27            IO17|- IO17
              IO14-|IO14/HSPI_CLK   IO16|- IO16
              IO12-|IO12/HSPI_MISO  IO4 |- IO4
              GND -|GND             IO0 |- IO0
              IO13-|IO13/HSPI_MOSI  IO2 |- IO2
              SD2 -|SD2             IO15|- IO15/HSPI_CS
              SD3 -|SD3             SD1 |- SD1
              CMD -|CMD             SD0 |- SD0
              5V  -|5V              CLK |- CLK
                   +--------------------+
                         USB-C PORT
```

#### Pin Categories
| Pin Category | Pin Numbers | Description |
|---|---|---|
| Power Pins | 3V3, 5V, GND | 3.3V and 5V power outputs, Ground pins |
| ADC Pins | IO32-IO39, IO0-IO5 | Analog-to-Digital Converter |
| DAC Pins | IO25, IO26 | Digital-to-Analog Converter |
| Touch Pins | IO0, IO2, IO4, IO12-IO15, IO27, IO32, IO33 | Capacitive touch sensors |
| SPI Pins | VSPI: IO5(CS), IO18(CLK), IO19(MISO), IO23(MOSI)<br>HSPI: IO15(CS), IO14(CLK), IO12(MISO), IO13(MOSI) | Serial Peripheral Interface |
| I2C Pins | IO21(SDA), IO22(SCL) | Inter-Integrated Circuit |
| UART Pins | UART0: IO1(TX), IO3(RX)<br>UART1: IO9(TX), IO10(RX)<br>UART2: IO16(TX), IO17(RX) | Serial communication |
| PWM Pins | All GPIOs | Pulse Width Modulation (software configurable) |

### 📡 Sensors:

#### 1. GY-BNO080 BNO085 AR VR IMU High Accuracy Nine-Axis 9DOF AHRS Sensor Module
GPS Antenna (https://s.click.aliexpress.com/e/_okDR7nd)
- **Purchase Link:** https://s.click.aliexpress.com/e/_okDR7nd
- **Model:** GY-BNO080 BNO085 AR VR IMU High Accuracy Nine-Axis 9DOF AHRS Sensor Module
- **Chipset:** Bosch BNO080 9-axis IMU with integrated sensor fusion
- **Interface:** I2C (primary) and SPI support
- **Sensors Integrated:**
  - **3-axis Accelerometer:** ±2g, ±4g, ±8g, ±16g selectable range
  - **3-axis Gyroscope:** ±250, ±500, ±1000, ±2000 dps selectable range
  - **3-axis Magnetometer:** Built-in compass functionality
- **Sensor Fusion:** Hardware-based AHRS (Attitude and Heading Reference System)
- **Output Data:**
  - Absolute orientation (quaternions, Euler angles)
  - Linear acceleration (gravity compensated)
  - Angular velocity
  - Magnetic heading
  - Calibrated sensor data
- **Resolution:** 16-bit for all sensors
- **Update Rate:** Up to 1000Hz (configurable, typically 100Hz for marine use)
- **Operating Voltage:** 3.3V (ESP32 compatible)
- **Current Consumption:** ~12.3mA typical operation
- **Temperature Range:** -40°C to +85°C (marine environment rated)
- **Calibration:** Automatic dynamic calibration with calibration status reporting
- **Marine Advantages:**
  - Single-chip solution eliminates sensor synchronization issues
  - Hardware sensor fusion provides stable, drift-free orientation
  - Built-in calibration algorithms for magnetic interference compensation
  - High accuracy suitable for precision sailing applications
- **Applications in this project:**
  - Real-time boat roll, pitch, and yaw measurement
  - Magnetic heading (compass) with automatic calibration
  - Heeling angle calculation for sailing optimization
  - Stability monitoring and motion analysis
  - True wind calculation support with attitude compensation

#### 2. RS485 Wind Sensor
Wind sensor (https://s.click.aliexpress.com/e/_onkySgT)
- **Purchase Link:** https://s.click.aliexpress.com/e/_onkySgT
- **Model:** Ultrasonic wind speed and direction sensor Miniature size Output RS485 Power supply 5 ~ 12V DC
- **Design:** Miniature size for compact marine installations
- **Interface:** RS485 Modbus RTU protocol
- **Communication:** Half-duplex serial communication at 9600 baud
- **Measurements:**
  - Wind Speed: 0-30 m/s (0-60 knots) ±0.3 m/s accuracy
  - Wind Direction: 0-359° ±3° accuracy
- **Update Rate:** 1-10 Hz configurable (1 second default for marine stability)
- **Operating Voltage:** 5-12V DC (lower power requirement than standard models)
- **Power Consumption:** <1W typical operation (energy efficient for marine use)
- **Operating Temperature:** -40°C to +80°C (marine grade)
- **Protection Rating:** IP65 (weather resistant for marine mounting)
- **Size Advantage:** Miniature design reduces wind resistance and installation complexity
- **Installation:** Masthead or deck mounting with clear 360° exposure
- **Cable Length:** Up to 1000m RS485 transmission distance
- **Applications in this project:**
  - Real-time apparent wind speed and direction
  - True wind calculation with GPS speed and heading
  - Wind trend analysis and logging
  - Sailing performance optimization data

#### 3. GPS Module
GPS Module (https://s.click.aliexpress.com/e/_onLOZmT)
- **Purchase Link:** https://s.click.aliexpress.com/e/_onLOZmT

GPS Antenna (https://s.click.aliexpress.com/e/_oExx7iF)
- **External Antenna (Optional):** https://s.click.aliexpress.com/e/_oExx7iF

- **Model:** GY-NEO8MV2 Module with Flight Control EEPROM MWC APM2.5
- **Chipset:** u-blox NEO-8M GNSS receiver
- **Interface:** UART serial communication (3.3V/5V compatible)
- **Antenna:** Built-in large ceramic patch antenna on PCB (can work standalone, but external antenna recommended for marine use)
- **EEPROM:** Built-in configuration storage for flight control applications
- **Data Format:** NMEA 0183 standard sentences (GGA, RMC, VTG, etc.)
- **Update Rate:** 1-10 Hz configurable (default 1Hz)
- **Accuracy:** <2.5 meters CEP (Circular Error Probable)
- **Sensitivity:** -167 dBm (excellent for marine conditions)
- **Acquisition:** Cold start <29s, Hot start <1s
- **Operating Voltage:** 3.3V-5V (ESP32 compatible)
- **Current Consumption:** ~45mA active, ~20mA backup mode
- **Temperature Range:** -40°C to +85°C (marine environment rated)
- **Supported Systems:** GPS, GLONASS, Galileo, BeiDou
- **Applications in planned features:**
  - Speed over ground (SOG) with high precision
  - Course over ground (COG) for navigation
  - Position fixing and track logging
  - True wind calculation with GPS speed compensation
  - Waypoint navigation and routing
  - Anchor drag alarm functionality
  - Time synchronization for data logging

### 🔌 Communication Modules:

#### RS485 to TTL Converter Module
RS485 Module (https://www.aliexpress.com/item/32688467460.html)
- **Purchase Link:** https://www.aliexpress.com/item/32688467460.html
- **Model:** MAX485 or SP3485 based converter
- **Function:** Convert ESP32 UART signals to RS485 differential signals
- **Interface:** 
  - TTL Side: 3.3V/5V UART (RX, TX, DE/RE)
  - RS485 Side: A+/B- differential pair
- **Operating Voltage:** 3.3V to 5V (ESP32 compatible)
- **Data Rate:** Up to 2.5 Mbps (more than sufficient for 9600 baud wind sensor)
- **Protection:** Built-in ESD protection for marine environment
- **Connections to ESP32:**
  - VCC → 3.3V or 5V
  - GND → Ground
  - DI (Data Input) → ESP32 TX pin
  - RO (Receiver Output) → ESP32 RX pin
  - DE/RE (Driver Enable/Receiver Enable) → ESP32 GPIO control pin
- **Connections to Wind Sensor:**
  - A+ → Wind sensor A+ (positive differential)
  - B- → Wind sensor B- (negative differential)
  - GND → Wind sensor ground (if available)

## System Architecture

### Data Flow:
1. **Sensors** → **ESP32** (collect and process data)
2. **ESP32** → **BLE** (transmit via Bluetooth Low Energy)
3. **BLE** → **Web Dashboard** (display real-time data)
4. **Web Dashboard** → **BLE** → **ESP32** (configuration commands)

### Power Management:
- **Input**: 5V via USB or external power
- **Consumption**: ~200mA typical, ~400mA peak
- **Low Power Mode**: Available for battery operation
- **Battery Monitoring**: ADC input for battery voltage

## Technical Specifications

### ESP32 Configuration:
- **Platform**: Espressif32 v6.4.0+
- **Framework**: Arduino
- **Build Flags**: Size optimized (-Os), PSRAM enabled
- **Memory Usage**: 11.6% RAM, 52.1% Flash

### BLE Configuration:
- **Service**: Custom sailing data service
- **Characteristics**: Wind, GPS, IMU, battery, configuration
- **Connection**: Up to 4 simultaneous connections
- **Range**: ~10-50 meters (enhanced with external antenna)
- **Marine Optimization**: External antenna provides superior performance in marine environments

### Sensor Interfaces:
- **I2C**: IMU sensor (SDA: GPIO21, SCL: GPIO22)
- **UART**: GPS module (RX: GPIO16, TX: GPIO17)
- **RS485**: Wind sensor (DE/RE: GPIO14, RX: GPIO32, TX: GPIO33)
- **Discovery Button**: GPIO0 (Built-in BOOT button)
- **Status LED**: GPIO2 (Built-in LED)
- **Anchor Light LED**: GPIO25 (Masthead LED control)

## Installation and Wiring

### ESP32 Pin Connections:
```
ESP32 DevKitC WROOM-32U Pinout:
┌─────────────────────────────┐
│  3V3  [ ][ ] VIN            │
│  GND  [ ][ ] GND            │
│  TX2  [ ][ ] GPIO13         │
│  RX2  [ ][ ] GPIO12         │
│GPIO22 [ ][ ] GPIO14         │ ← I2C SCL (IMU) / RS485 DE/RE
│GPIO21 [ ][ ] GPIO27         │ ← I2C SDA (IMU)
│GPIO17 [ ][ ] GPIO26         │ ← UART TX (GPS)
│GPIO16 [ ][ ] GPIO25         │ ← UART RX (GPS)
│GPIO4  [ ][ ] GPIO33         │                   / RS485 TX
│GPIO0  [ ][ ] GPIO32         │ ← BOOT Button     / RS485 RX
│GPIO2  [ ][ ] GPIO35         │ ← Status LED
│GPIO15 [ ][ ] GPIO34         │
│GPIO8  [ ][ ] GPIO39         │
│GPIO7  [ ][ ] GPIO36         │
│GPIO6  [ ][ ] EN             │
│GPIO5  [ ][ ] 3V3            │
│  GND  [ ][ ] GND            │
└─────────────────────────────┘
```

### Sensor Wiring:

#### IMU Sensor (BNO080):
```
BNO080  →  ESP32
VCC     →  3.3V
GND     →  GND
SDA     →  GPIO21
SCL     →  GPIO22
```

#### GPS Module:
```
GPS     →  ESP32
VCC     →  3.3V or 5V
GND     →  GND
TX      →  GPIO16 (RX2)
RX      →  GPIO17 (TX2)
```

#### Wind Sensor (RS485):
```
RS485   →  ESP32
A+      →  GPIO33 (via RS485 transceiver)
B-      →  GPIO32 (via RS485 transceiver)
DE/RE   →  GPIO14
VCC     →  5-12V DC (5V power bank compatible)
GND     →  GND
```

## Development Environment

### Build Configuration:
- **Memory**: 38KB RAM, 683KB Flash used
- **Libraries**: All dependencies automatically managed
- **Build Time**: ~16 seconds for full build
- **Upload**: ~10 seconds via USB

### Development Tools:
- **VS Code** with PlatformIO extension
- **Task Buttons** for one-click build/upload
- **Serial Monitor** for debugging
- **Web Dashboard** for testing BLE communication

## Features Implementation

### Real-time Data Streaming:
- **GPS Data**: Position, SOG, COG, satellite count
- **Wind Data**: Apparent wind speed/direction, true wind calculations
- **Heel Data**: Roll, pitch, yaw from IMU sensor fusion
- **System Data**: Battery voltage, connection status, error states

### Device Configuration:
- **Sensor Calibration**: Wind direction offset, magnetic declination
- **Update Rates**: Configurable sensor polling intervals  
- **Device Settings**: BLE name, connection parameters
- **Factory Reset**: Restore all settings to defaults

### Error Handling:
- **Sensor Monitoring**: Automatic detection of failed sensors
- **Graceful Degradation**: Continue operation with available sensors
- **Status Reporting**: Error codes transmitted via BLE
- **Watchdog Timer**: Automatic recovery from system hangs

## Performance Specifications

### Data Rates:
- **GPS Updates**: 1Hz (configurable up to 10Hz)
- **IMU Updates**: 10Hz (configurable up to 100Hz)  
- **Wind Updates**: 5Hz (configurable up to 20Hz)
- **BLE Transmission**: 10Hz combined data stream

### Power Consumption:
- **Active Mode**: ~200mA @ 5V
- **Peak Load**: ~400mA during BLE transmission
- **Sleep Mode**: ~50μA (future implementation)
- **Battery Life**: 8-12 hours with 2000mAh power bank

### Environmental Specs:
- **Operating Temperature**: -10°C to +60°C
- **Humidity**: 0-95% non-condensing
- **Water Resistance**: IP65 with proper enclosure
- **Vibration**: Marine environment tested

This hardware platform provides a robust foundation for comprehensive sailing data monitoring with modern web-based visualization.

## Related Documentation

For software interface and protocol details, see:

- **[Setup Guide](./SETUP.md)** - User instructions for connecting and using the hardware
- **[Development Guide](./DEVELOPMENT.md)** - Software development workflow
- **[Firmware Documentation](../firmware/readme.md)** - BLE protocol and firmware implementation details

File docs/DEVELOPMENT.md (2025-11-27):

# Veetr - Development Guide

Development workflow and setup instructions for contributors and developers working on the Veetr project.

## Related Documentation

This development guide is the primary resource for contributors. For specific technical details, also see:

- **[Setup Guide](./SETUP.md)** - User-focused hardware and software setup
- **[Hardware Guide](./HARDWARE.md)** - ESP32 wiring, sensor specifications, and pin assignments
- **[PlatformIO Guide](./PLATFORMIO.md)** - PlatformIO configuration and troubleshooting
- **[Firmware Documentation](../firmware/readme.md)** - ESP32 implementation details and BLE protocol
- **[Version Management](./VERSION_MANAGEMENT.md)** - Release process and automated workflows

## Quick Development Setup ⚡

### 1. Setup Development Environment
```bash
git clone https://github.com/escopecz/veetr.git
cd veetr
code veetr.code-workspace
```

### 2. Use VS Code Tasks
The workspace is configured with tasks for development. Access via:
- **Ctrl+Shift+P** → "Tasks: Run Task" → Select task
- **Terminal** → "Run Task..." menu

Available tasks:
- **Web: Dev Server** - Start React development server
- **Firmware: Build** - Build ESP32 firmware  
- **Firmware: Upload** - Upload firmware to ESP32
- **Firmware: Monitor** - Open serial monitor

### 3. Manual Commands
```bash
# Web development
cd app && npm install && npm run dev

# Firmware development  
pio run                    # Build
pio run --target upload    # Upload to ESP32
pio device monitor         # Serial monitor
```

## Development Workflow

### Daily Development Process:
1. **🌐 Start App Dev Server** - Run "App: Dev Server" task or `cd app && npm run dev`
2. **⚡ Build Firmware** - Run "Firmware: Build" task or `pio run`
3. **📤 Upload to ESP32** - Run "Firmware: Upload" task or `pio run --target upload` 
4. **📺 Monitor Serial** - Run "Firmware: Monitor" task or `pio device monitor`
5. **🔘 Activate Discovery** - Press and hold BOOT button (GPIO0) for 1+ seconds
6. **🔗 Test BLE Connection** - Open dashboard and connect to ESP32

### Code Organization

#### Web Application (\`/app\`)
- **React 18** + TypeScript + Vite
- **Tailwind CSS** for styling
- **Web Bluetooth API** for BLE communication
- **PWA** capabilities for mobile installation

#### ESP32 Firmware (`/firmware`)
- **Arduino Framework** via PlatformIO
- **NimBLE** for Bluetooth Low Energy
- **Sensor Integration**: GPS, IMU, Wind sensors ([hardware specs](./HARDWARE.md))
- **Communication**: UART/I2C/RS485 protocols

### PWA Health Monitoring System

The web application includes an advanced health monitoring system designed for long sailing sessions, especially on Android tablets:

#### Automatic Monitoring Features:
- **Memory Management**: Monitors JavaScript heap usage and triggers garbage collection when >80%
- **BLE Connection Watchdog**: Detects disconnected devices and attempts automatic reconnection
- **Long Session Tracking**: Special monitoring for sessions >1 hour with detailed logging
- **Service Worker Health**: Monitors PWA service worker status and cache integrity
- **Background Cleanup**: Handles stale connections and prevents memory leaks

#### Recovery Systems:
- **Automatic Recovery**: Proactive garbage collection and connection cleanup
- **Manual Recovery Tools**: User-accessible PWA refresh and diagnostics
- **Progressive Escalation**: Failure count tracking with escalating recovery options
- **Connection Diagnostics**: Detailed BLE and PWA status logging for troubleshooting

#### Implementation Details:
- Health checks run every 60 seconds when in PWA standalone mode
- Only activates on installed PWAs to avoid overhead in browser mode
- Comprehensive error handling prevents monitoring system from causing issues
- Detailed console logging for debugging Android tablet stability issues

### Development Tasks

#### Web Development
```bash
# Start development server
npm run dev

# Build for production
npm run build

# Preview production build
npm run preview

# Run linting
npm run lint

# Format code
npm run format
```

#### Firmware Development
```bash
# Build firmware
pio run

# Upload to ESP32
pio run --target upload

# Monitor serial output
pio device monitor

# Clean build files
pio run --target clean

# Upload filesystem (if needed)
pio run --target uploadfs
```

### Testing Workflow

#### Hardware Testing:
1. Build and upload firmware to ESP32
2. Activate BLE discovery mode (BOOT button)
3. Connect via web dashboard
4. Verify sensor data streams
5. Test configuration commands

#### Web Testing:
1. Start development server
2. Test in Chrome/Edge (Web Bluetooth supported)
3. Verify PWA installation
4. Test responsive design on mobile devices
5. Validate BLE connectivity

### Code Quality

#### Pre-commit Checklist:
- [ ] Code passes TypeScript compilation
- [ ] Firmware builds without errors
- [ ] No console errors in web browser
- [ ] BLE communication works
- [ ] Responsive design validated
- [ ] Documentation updated if needed

#### Standards:
- **TypeScript**: Strict mode enabled
- **ESLint**: Configured for React/TypeScript
- **Prettier**: Code formatting
- **Git**: Conventional commit messages

### Debugging Tips

#### Web Dashboard:
- Use Chrome DevTools for Web Bluetooth debugging
- Check Network tab for PWA service worker issues
- Console shows BLE connection status and errors

#### ESP32 Firmware:
- Serial monitor shows sensor readings and BLE status
- Built-in LED indicates discovery mode status
- Watchdog timer prevents system hangs

#### Common Issues:
- **BLE not found**: Activate discovery mode on ESP32
- **Build errors**: Check PlatformIO installation
- **Web not connecting**: Ensure HTTPS or localhost
- **Sensor errors**: Check wiring and power supply

### Contributing

#### Pull Request Process:
1. Fork the repository
2. Create feature branch (`git checkout -b feature/amazing-feature`)
3. Make changes and test thoroughly
4. Commit changes (`git commit -m 'Add amazing feature'`)
5. Push to branch (`git push origin feature/amazing-feature`)
6. Open Pull Request

#### Code Review:
- All code changes require review
- Tests must pass
- Documentation must be updated
- Hardware changes need validation

### Development Environment

#### Recommended VS Code Extensions:
- **PlatformIO IDE** - ESP32 development
- **TypeScript and JavaScript Language Features**
- **Tailwind CSS IntelliSense**
- **Prettier** - Code formatting
- **GitLens** - Git integration
- **Auto Rename Tag** - HTML/JSX editing
- **Bracket Pair Colorizer** - Code readability

#### System Requirements:
- **Node.js** v16+ (for app development)
- **Python** 3.7+ (for PlatformIO)
- **Git** (version control)
- **USB drivers** for ESP32 (platform specific)

This development guide provides everything needed for productive Veetr development!

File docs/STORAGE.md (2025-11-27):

# Data Storage - Veetr

Documentation for data storage, persistence, and logging in the Veetr system.

## Storage Architecture

### 🌐 Web Dashboard Storage

The web dashboard uses browser-based storage for user preferences and session data:

#### Local Storage:
- **Connection settings** - Previously paired BLE devices
- **User preferences** - Dashboard layout, units, themes
- **Calibration data** - Wind direction offset, magnetic declination
- **Session state** - Last known device connection

#### Session Storage:
- **Real-time data buffer** - Recent sailing data for smooth animations
- **Chart data** - Historical data points for graphs and trends
- **Connection status** - Current BLE connection state

#### Implementation:
```typescript
// Location: app/src/utils/storage.ts
// Location: app/src/hooks/useSailingStorage.ts
```

### ⚡ ESP32 Firmware Storage

The ESP32 uses EEPROM/NVS (Non-Volatile Storage) for persistent configuration:

#### EEPROM Storage:
- **Device configuration** - Sensor calibration values
- **Network settings** - WiFi credentials (if used)
- **BLE settings** - Device name, pairing information
- **Sensor offsets** - Wind direction calibration, compass deviation

#### Flash Storage:
- **Firmware updates** - OTA update staging area
- **Log buffer** - Error logs and debug information
- **Historical data** - Trip logs, max values, statistics

#### Implementation:
```cpp
// Location: firmware/src/main.cpp
// Uses: Preferences library for NVS access
```

## Data Flow

### Real-time Data:
1. **ESP32 sensors** ([hardware details](./HARDWARE.md)) → **BLE transmission** → **Web dashboard**
2. **Web storage** for immediate display and short-term buffering
3. **No persistent logging** of real-time data (by design)

### Configuration Data:
1. **Web interface** → **BLE commands** → **ESP32 storage**
2. **ESP32 EEPROM** preserves settings across power cycles
3. **Web localStorage** caches settings for faster UI response

## Storage Limits

### Web Dashboard:
- **LocalStorage**: ~5-10MB per domain (browser dependent)
- **SessionStorage**: ~5-10MB per tab session
- **IndexedDB**: Available for future expansion (large data sets)

### ESP32 Firmware:
- **NVS Partition**: 16KB (configurable in platformio.ini)
- **SPIFFS**: 1.5MB available for file storage
- **EEPROM**: 512 bytes (compatibility mode)

## Data Privacy

### Local-Only Storage:
- **No cloud storage** - all data remains on device
- **No telemetry** - no data transmitted to external servers
- **BLE only** - direct device-to-device communication

### Data Retention:
- **Real-time data**: Cleared on page refresh
- **Settings**: Persist until manually cleared
- **Logs**: Rotate automatically when storage fills

## Configuration Management

### Calibration Data:
```typescript
interface CalibrationSettings {
  windDirectionOffset: number;    // Degrees to add to wind direction
  magneticDeclination: number;    // Local magnetic declination
  heelCalibration: number;        // Heel angle zero point
  compassDeviation: number[];     // Compass deviation table
}
```

### Device Settings:
```cpp
struct DeviceConfig {
  char deviceName[32];           // BLE device name
  uint16_t updateRate;           // Data update rate (ms)
  bool gpsEnabled;               // GPS module enable/disable
  bool imuEnabled;               // IMU module enable/disable
  float sensorOffsets[8];        // Various sensor calibration offsets
};
```

## Backup and Restore

### Web Dashboard:
- **Export settings**: Download JSON file with all preferences
- **Import settings**: Upload JSON file to restore configuration
- **Reset to defaults**: Clear all localStorage data

### ESP32 Firmware:
- **Factory reset**: Clear all NVS storage via BLE command
- **Backup via BLE**: Read all settings through web interface
- **Restore via BLE**: Write settings from web interface

## Future Enhancements

### Planned Storage Features:
- **Trip logging**: Store sailing sessions with GPS tracks
- **Performance analytics**: Historical speed/wind data analysis
- **Cloud sync**: Optional backup to user's cloud storage
- **Export formats**: GPX, CSV, JSON data export

### Technical Improvements:
- **Data compression**: Efficient storage of time-series data
- **Automatic cleanup**: Smart storage management and rotation
- **Encryption**: Secure storage of sensitive configuration data
- **Versioning**: Configuration migration for firmware updates

## Implementation Files

### Web Dashboard:
- `app/src/utils/storage.ts` - Storage utilities and helpers
- `app/src/hooks/useSailingStorage.ts` - React hook for sailing data storage
- `app/src/context/BLEContext.tsx` - BLE connection and data management

### ESP32 Firmware:
- `firmware/src/main.cpp` - Main firmware with storage functions
- Storage libraries: `Preferences`, `SPIFFS`, `ArduinoJson`

This storage architecture ensures reliable data persistence while maintaining user privacy and device performance.

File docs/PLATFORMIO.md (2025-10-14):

# PlatformIO Configuration for Veetr

This project uses PlatformIO for ESP32 firmware development with a unified configuration at the root level.

## Project Structure

```
veetr/
├── platformio.ini           # PlatformIO configuration (root level)
├── firmware/
│   ├── src/                 # Source code
│   ├── include/             # Header files
│   ├── lib/                 # Custom libraries
│   └── test/                # Test files
└── .vscode/
    └── tasks.json           # VS Code tasks for PlatformIO
```

## Configuration Details

### Target Hardware:
- **Board**: ESP32 DevKitC WROOM-32U ([detailed specs](./HARDWARE.md))
- **Platform**: Espressif32 v6.4.0+
- **Framework**: Arduino
- **Monitor Speed**: 115200 baud

### Installed Libraries:
- **ArduinoJson** v6.21.2+ - JSON serialization
- **SparkFun BNO080** - IMU/orientation sensor
- **TinyGPSPlus** v1.0.3+ - GPS data parsing
- **ModbusMaster** v2.0.1+ - RS485 sensor communication
- **NimBLE-Arduino** v1.4.2+ - Bluetooth Low Energy

### Build Flags:
- **Debug Level**: 1 (minimal debug output)
- **PSRAM Support**: Enabled for additional memory
- **Optimization**: `-Os` (size optimization)
- **BLE Configuration**: 4 max connections, optimized logging

## Development Workflow

For complete development setup and daily workflow, see the **[Development Guide](./DEVELOPMENT.md)**.

This document focuses on PlatformIO-specific configuration and troubleshooting.

## Build Commands Reference

From the root directory (not the firmware subdirectory):
```bash
pio run                    # Build firmware
pio run --target upload    # Upload to ESP32
pio device monitor         # Serial monitor
pio run --target clean     # Clean build files
```

## PlatformIO IDE Integration
For full PlatformIO IDE experience:
```bash
cd firmware && code .
```
This opens the firmware folder as a dedicated PlatformIO project.

## Memory Usage

Current firmware uses approximately:
- **RAM**: 11.6% (38,076 / 327,680 bytes)
- **Flash**: 52.1% (683,397 / 1,310,720 bytes)

Plenty of space remaining for additional features and sensors ([see sensor options](./HARDWARE.md)).

## Adding New Libraries

To add a new library, edit `platformio.ini`:
```ini
lib_deps = 
    bblanchon/ArduinoJson @ ^6.21.2
    # ... existing libraries ...
    your-new-library @ ^1.0.0
```

Then rebuild with **⚡ FW Build** button or `pio run`.

## Debugging

### Serial Monitor:
- Click **📺 Monitor** button in VS Code
- Or run: `pio device monitor`
- Baud rate: 115200

### Debug Output:
The firmware includes debug logging. Adjust debug level in `platformio.ini`:
```ini
build_flags = 
    -DCORE_DEBUG_LEVEL=3    # 0=None, 1=Error, 2=Warn, 3=Info, 4=Debug, 5=Verbose
```

## Troubleshooting

### Upload Issues:
1. Check USB cable connection
2. Ensure correct port is detected
3. Press ESP32 reset button during upload if needed
4. Try different USB cable or port

### Build Errors:
1. Clean build: **🧹 Clean** button or `pio run --target clean`
2. Update PlatformIO: `pio update`
3. Check library compatibility in `platformio.ini`

### Library Issues:
1. Clear library cache: `pio lib -g update`
2. Reinstall libraries: Delete `.pio/libdeps/` folder and rebuild

## Advanced Configuration

### Custom Build Environments:
Add new environments to `platformio.ini`:
```ini
[env:debug]
board = esp32doit-devkit-v1
build_flags = 
    -DCORE_DEBUG_LEVEL=5
    -DDEBUG_MODE=1

[env:production]
board = esp32doit-devkit-v1  
build_flags = 
    -DCORE_DEBUG_LEVEL=0
    -Os
```

### OTA Updates:
For over-the-air firmware updates, add OTA configuration:
```ini
upload_protocol = espota
upload_port = 192.168.1.100  # ESP32 IP address
```

## VS Code Integration

The project includes optimized VS Code settings:
- **PlatformIO IDE** extension integration
- **Auto-completion** for ESP32 Arduino framework
- **Intellisense** for all project libraries
- **Task buttons** for common operations

This provides a seamless development experience without leaving VS Code.

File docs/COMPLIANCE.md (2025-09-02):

# Compliance and Certifications

This document outlines the regulatory compliance and certifications for the Veetr device.

## ESP32 Module Certifications

The Veetr system is built around the ESP32-WROOM-32U module, which holds the following certifications:

### FCC Certification (United States)
- **FCC ID**: 2AC7Z-ESP32WROOM32U
- **Module**: ESP32-WROOM-32U
- **Manufacturer**: Espressif Systems
- **Compliance**: FCC Part 15, Subpart C (15.247)
- **Frequency**: 2.412-2.484 GHz (Wi-Fi/Bluetooth)

### IC Certification (Canada)
- **IC ID**: 21098-ESP32WROOM32U
- **Module**: ESP32-WROOM-32U
- **Compliance**: RSS-247 Issue 2

### CE Marking (European Union)
- **Module**: ESP32-WROOM-32U
- **Standards**: EN 300 328, EN 301 489, EN 62479
- **Directives**: 2014/53/EU (Radio Equipment Directive)

## Regulatory Compliance

### ESP32 Module Compliance

The Veetr project is based on the **ESP32-WROOM-32U** module, which holds the following pre-existing certifications:

**FCC (United States)**: FCC ID 2AC7Z-ESP32WROOM32U
**IC (Canada)**: IC ID 21098-ESP32WROOM32U  
**CE (European Union)**: Compliant with RED 2014/53/EU

### Compliance Approach

**For DIY Builders:**
- Use only certified ESP32-WROOM-32U modules with valid markings
- Personal use devices generally exempt from additional certification
- Follow the reference design and specified antenna configurations
- Check local regulations for personal electronics

**For Commercial Kit Sales:**
- ESP32 module certification typically covers radio compliance when used as designed
- Kit sellers should verify they're following the certified module configuration
- Additional certification may be required for significant modifications or specific markets
- Consult regulations in target markets - requirements vary significantly by region

### Important Notes

This open hardware project does **not** provide product certifications. The compliance information refers only to the ESP32 module used in the design. Anyone building or selling Veetr devices is responsible for ensuring compliance in their jurisdiction.

## FCC Compliance Statement

### United States - FCC Part 15

This device complies with Part 15 of the FCC Rules. Operation is subject to the following two conditions:
1. This device may not cause harmful interference
2. This device must accept any interference received, including interference that may cause undesired operation

**FCC Warning:**
Changes or modifications not expressly approved by the party responsible for compliance could void the user's authority to operate the equipment.

**RF Exposure Information:**
This equipment complies with FCC radiation exposure limits set forth for an uncontrolled environment. This equipment should be installed and operated with minimum distance of 20 cm between the radiator and your body.

**Modular Approval:**
This product contains FCC ID: 2AC7Z-ESP32WROOM32U. The modular device complies with FCC Part 15 rules.

## Canada - IC Compliance

### Innovation, Science and Economic Development Canada (ISED)

This device complies with Innovation, Science and Economic Development Canada licence-exempt RSS standard(s). Operation is subject to the following two conditions:
1. This device may not cause interference
2. This device must accept any interference, including interference that may cause undesired operation of the device

**IC Warning:**
This device complies with IC RSS-102 radiation exposure limits set forth for an uncontrolled environment.

**French (Canada):**
Le présent appareil est conforme aux CNR d'Industrie Canada applicables aux appareils radio exempts de licence. L'exploitation est autorisée aux deux conditions suivantes:
1. L'appareil ne doit pas produire de brouillage
2. L'utilisateur de l'appareil doit accepter tout brouillage radioélectrique subi, même si le brouillage est susceptible d'en compromettre le fonctionnement

## Additional Compliance Notes

### Open Source Hardware Project
- **Open Design**: All hardware designs, schematics, and code are open source
- **DIY Building**: Individuals can build devices for personal use from published designs
- **Component Sourcing**: Builders should source certified ESP32 modules from authorized distributors
- **Personal Use Exemption**: Most jurisdictions exempt personal-use devices from certification requirements

### Commercial Kit Sales
- **Kit Certification**: Commercial kit sellers must obtain appropriate certifications for their market
- **Quality Control**: Kit manufacturers responsible for component quality and compliance verification
- **Documentation**: Must provide compliance documentation and assembly instructions
- **Support**: Kit sellers should provide technical support and warranty coverage

### Certification Scope
- **Module-Based Design**: Relies on pre-certified ESP32-WROOM-32U modules
- **Low-Power Sensors**: Additional sensors (GPS, IMU, wind) operate below regulatory thresholds
- **External Power**: Uses external 5V USB-C power supply (not subject to radio regulations)
- **Antenna Compliance**: Must use antennas matching ESP32 module certification

### Regional Variations
- Different countries may have additional requirements
- Consult local regulatory authorities for specific market requirements
- Some markets may require local representative or importer registration

## Disclaimer

**This document is for reference only.** The Veetr project:

- **Does NOT provide product certifications** for complete devices
- **Only references** existing ESP32 module certifications
- **Is an open hardware design** - builders are responsible for their own compliance
- **Cannot guarantee compliance** of derivative works or modifications

**Users building or selling Veetr devices must:**

1. Verify current certification status of all components
2. Obtain independent legal and regulatory advice
3. Secure appropriate certifications for commercial sales
4. Ensure compliance with local regulations
5. Use only certified components matching the reference design

**Note:** This documentation does not constitute legal advice. Regulatory requirements vary by jurisdiction and application. The ESP32 module certifications referenced here belong to Espressif Systems, not the Veetr project.

## References

- [ESP32-WROOM-32U Datasheet](https://www.espressif.com/sites/default/files/documentation/esp32-wroom-32d_esp32-wroom-32u_datasheet_en.pdf)
- [FCC Equipment Authorization Database](https://www.fcc.gov/oet/ea/fccid)
- [ISED Equipment Database](https://sms-sgs.ic.gc.ca/equipmentSearch/searchRadioEquipments)
- [EU Radio Equipment Database](https://ec.europa.eu/growth/tools-databases/radio-equipment-database/)

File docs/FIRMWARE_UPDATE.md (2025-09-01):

# Firmware Update Guide

This guide explains how to update the Veetr sailing dashboard firmware to the latest version.

## 🔄 Automatic Update (Recommended)

The easiest way to update your firmware is through the web dashboard's built-in OTA (Over-The-Air) update feature:

1. **Connect to your ESP32** via Bluetooth in the web dashboard
2. **Go to Settings** → **Firmware Update**
3. **Click "Check for Updates"**
4. If a newer version is available, **click "Update Firmware"**
5. **Wait for the update to complete** (do not disconnect during this process)

## 📦 Manual Installation

If the automatic update doesn't work or you prefer manual installation:

### Understanding the Files

When you download a release, you'll see several files:

- **`veetr-X.X.X.bin`** - The firmware binary to flash to your ESP32
- **`veetr-X.X.X.elf`** - Debug symbols file (only needed for development/debugging crashes)
- **`firmware-info.json`** - Build metadata (version, date, size, etc.)

**For normal users**: You only need the `.bin` file.

### Option 1: Using ESPTool (Recommended)

1. **Download the latest firmware** from the [releases page](https://github.com/escopecz/veetr/releases)
2. **Install ESPTool** if you haven't already:
   ```bash
   pip install esptool
   ```
3. **Connect your ESP32** to your computer via USB
4. **Flash the firmware**:
   ```bash
   esptool.py --port /dev/ttyUSB0 write_flash 0x10000 veetr-X.X.X.bin
   ```
   
   > **Note**: Replace `/dev/ttyUSB0` with your actual port (on Windows it might be `COM3`, on macOS `/dev/tty.usbserial-*`)

### Option 2: Using PlatformIO

If you have the source code and PlatformIO installed:

1. **Clone the repository**:
   ```bash
   git clone https://github.com/escopecz/veetr.git
   cd veetr
   ```
2. **Checkout the desired version**:
   ```bash
   git checkout X.X.X  # Replace with the version tag
   ```
3. **Upload to your ESP32**:
   ```bash
   pio run --target upload
   ```

## 🔍 Verification

After updating, you can verify the firmware version by:

1. **Connecting to the web dashboard**
2. **Going to Settings** → **System Info**
3. **Checking the firmware version** displayed

## ⚠️ Troubleshooting

### Update Failed
- Ensure your ESP32 is properly connected via Bluetooth
- Try refreshing the web dashboard page
- Check that your device has sufficient battery/power
- Try the manual installation method

### Connection Issues
- Make sure Bluetooth is enabled on your device
- **Activate Discovery Mode**: Press and hold the BOOT button (GPIO0) for 1+ seconds
- Verify the built-in LED (GPIO2) turns on to confirm discovery mode is active
- Clear your browser cache and try again
- Check that the ESP32 is powered on and in discovery mode (LED should be on)

### Manual Installation Issues
- Verify the correct port/COM number for your ESP32
- Ensure no other programs are using the serial port
- Try pressing the BOOT button on the ESP32 while connecting

## 📞 Support

If you encounter issues:

1. Check the [Issues page](https://github.com/escopecz/veetr/issues) for known problems
2. Create a new issue with details about your problem
3. Include your firmware version, device type, and error messages

---

**Always backup your settings before updating firmware!**

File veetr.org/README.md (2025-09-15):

# Veetr.org Website

This folder contains the static website files for https://veetr.org

## Structure

- `index.html` - Main landing page
- `styles.css` - Stylesheet with all CSS styling
- `CNAME` - GitHub Pages custom domain configuration for veetr.org
- Additional assets can be added here as needed

## Deployment

The site is automatically mirrored to the [veetr-site repository](https://github.com/escopecz/veetr-site) via GitHub Actions when changes are made to this folder.

## Development

To test the site locally:
1. Open `index.html` directly in a web browser
2. Or serve via a local web server:
   ```bash
   # Python 3
   python3 -m http.server 8000
   
   # Node.js (if installed)
   npx http-server
   
   # PHP (if installed)
   php -S localhost:8000
   
   # macOS with Python 2 (legacy)
   python -m SimpleHTTPServer 8000
   ```
3. Then visit `http://localhost:8000`

## Features

The landing page includes:
- Hero section with project overview
- Feature highlights
- Technical specifications
- Links to all documentation
- Responsive design for mobile and desktop
- Modern CSS with smooth animations
- SEO optimized with meta tags

## Customization

The site uses external CSS for better maintainability. Key design elements:
- Color scheme: Blue gradient (#667eea to #764ba2)
- Font: System font stack for performance
- Layout: CSS Grid and Flexbox for responsiveness
- Icons: Unicode emoji for simplicity

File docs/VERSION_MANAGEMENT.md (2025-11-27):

# Version Management

This project uses centralized version management with the root `package.json` as the single source of truth.

## Current Version System

- **Source of Truth**: `/package.json` version field
- **Web App**: Synced to `/app/package.json` and `/app/src/utils/version.ts`
- **Firmware**: Synced to `#define FIRMWARE_VERSION` in `/firmware/src/main.cpp`

## How to Create a Release (Recommended)

### 🚀 Automated Release Process
```bash
./veetr release 0.0.1   # Creates branch, commits, tags, and pushes
```

**What this does automatically:**
1. ✅ Validates the version format (semver)
2. ✅ Checks git working directory is clean
3. ✅ Updates all version references
4. ✅ Commits directly to main with message `"Bump to version 0.0.1"`
5. ✅ Creates and pushes git tag `0.0.1`
6. ✅ Pushes changes to main branch

**GitHub Actions will then:**
1. 🔍 Validate version consistency across all files
2. 🏗️ Build web app and firmware to ensure no errors
3. 🎉 Create GitHub release with binaries automatically

## Complete Release Workflow

### Using Automated Release (Recommended)
```bash
# 1. Create release (does everything automatically)
./veetr release 1.2.3

# 2. GitHub Actions automatically validates, builds, and creates release
# 3. Done! Check the releases page for your new release
```

## GitHub Actions Automation

### On Tag Creation:
- **Validates**: All files have consistent versions
- **Builds**: Web app and firmware 
- **Creates**: GitHub release with firmware binaries
- **Reports**: Success/failure with detailed information

## Troubleshooting

### Release Command Fails
- Ensure git working directory is clean: `git status`
- Check you're on the main branch: `git branch`
- Verify version format: use semver like `1.2.3`

### Version Inconsistency
- The veetr CLI now includes built-in version synchronization
- Check the validation output in GitHub Actions

### GitHub Actions Fails
- Check the workflow logs for specific errors
- Ensure all files build successfully locally

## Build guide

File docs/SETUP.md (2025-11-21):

# Veetr Sailing Dashboard - User Setup Guide

Step-by-step instructions for sailors to get their Veetr sailing dashboard up and running.

## What You Need 🛒

### Required Hardware:
See the **[Hardware Guide](./HARDWARE.md)** for detailed specifications and purchase links.

### Supported Devices:
- **iPhone/iPad**: Must use [Bluefy - Web BLE Browser](https://apps.apple.com/app/bluefy-web-ble-browser/id1492822055) (Safari doesn't support Bluetooth)
- **Android**: Any device with Chrome, Edge, or Opera browser
- **Computer**: Windows, Mac, or Linux with Chrome, Edge, or Opera

## Setup Steps 🔧

### 1. Get Veetr Dashboard App

**Visit the web app**: https://app.veetr.org

**Install as a real app (recommended):**

**📱 iPhone/iPad (iOS):**
- **Important**: iOS Safari doesn't support Web Bluetooth
- **Download**: [Bluefy - Web BLE Browser](https://apps.apple.com/app/bluefy-web-ble-browser/id1492822055) from App Store
- **Open**: https://app.veetr.org in Bluefy
- Sadly, iOS users will get the worst experience due to the OS limitations. We should fix that with a custom app in the future.

**📱 Android Phone/Tablet:**
- **Open**: Chrome browser (pre-installed)
- **Visit**: https://app.veetr.org
- **Install**: Tap menu (⋮) → "Add to Home screen" → "Add"
- **Alternative**: Look for "Install app" banner at bottom of screen

**💻 Windows Computer:**
- **Open**: Chrome or Edge browser
- **Visit**: https://app.veetr.org
- **Install**: Click install icon (⊞) in address bar → "Install"
- **Alternative**: Click menu (⋮) → "Install Veetr..."

**💻 Mac Computer:**
- **Open**: Chrome, Edge, or Safari browser
- **Visit**: https://app.veetr.org
- **Chrome/Edge**: Click install icon (⊞) in address bar → "Install"
- **Safari**: Click Share → "Add to Dock"

**💻 Linux Computer:**
- **Open**: Chrome, Chromium, or Firefox browser
- **Visit**: https://app.veetr.org
- **Chrome/Chromium**: Click install icon (⊞) in address bar → "Install"
- **Firefox**: Click menu → "Install this site as an app"

### 2. Prepare the Veetr device

1. Position the GPS module (has built-in antenna, external antenna optional for better reception)
2. Connect the BLE (Bluetooth Low Energy) antenna
3. Connect the wind sensor via the RJ45 connector

### 3. Connect to Your Boat 🔗

**First Time Setup:**
1. **Power on the Veetr device** (connect to a powerbank via USB C)
2. **Activate Discovery Mode**: The device is in the discovery mode 5 minutes after start
3. **Check Status**: The built-in blue LED turn on when the discovery mode active. It turns off after 5 minutes for security.
4. **Open Dashboard**: Launch the Veetr app on your device
5. **Connect**: Tap **"Connect"** button
6. **Select Device**: Choose "Veetr" from the Bluetooth list
7. **Start Sailing**: Watch your real-time sailing data! ⛵

**Daily Use:**
- Discovery mode turns off automatically after 5 minutes for security
- Press BOOT button again anytime to reconnect
- You have to connect the device in the app again.

### Calibration

Once your Veetr is connected and showing data, you'll want to calibrate it for accurate readings.

#### **Heel Angle Calibration** ⚖️

You don't have to mount the Veetr device exactly level to the boat. Mount it firmly though so it doesn't move so the calibration actually lasts. It must at the same position every time. Otherwise you'll have to re-calibrate.

**When to calibrate**: When your boat is completely level (flat water, no wind pressure)

1. **Level your boat**: Find calm water or secure the boat level at dock/mooring
2. **Open Settings**: In the Veetr dashboard, go to Settings tab
3. **Calibrate**: Click the "Vessel is level" button
4. **Wait**: Allow 5 seconds for calibration to complete
5. **Done**: The heel angle will now show 0° when your boat is level

**Why important**: Sets the "zero point" so heel angles are accurate relative to your boat's level position.

#### **Wind Direction Calibration** 💨
**When to calibrate**: After mounting the wind sensor

1. **Mount correctly**: Install wind sensor with arrow pointing toward bow (front) of boat

**Why important**: Ensures wind direction readings are relative to your boat's heading.

#### **Compass Calibration** 🧭
**Manual calibration required**: Set your compass north reference for accurate heading readings

1. **Point to North**: Turn your boat so the bow (front) points toward magnetic north
2. **Open Settings**: In the Veetr dashboard, go to Settings tab
3. **Calibrate**: Click "Set Compass North" button
4. **Confirm**: The app will ask for confirmation - press OK
5. **Done**: Your current heading is now set as north (0°)

**Why important**: Sets the magnetic north reference so compass headings are accurate relative to true directions.

#### **GPS Calibration** 🛰️
**Automatic**: GPS requires no calibration
- **Built-in antenna**: The GPS module has a built-in ceramic patch antenna and can work without external antenna
- **External antenna (optional)**: For improved reception in challenging conditions, an external active antenna can be connected via U.FL connector
- **Module positioning**: Mount GPS module with antenna side facing upward with clear view of sky
- **Avoid obstructions**: Keep away from metal surfaces, masts, and cabin tops that block satellite signals
- **Satellite acquisition**: Allow 1-2 minutes for initial GPS lock after positioning
- **No manual steps**: GPS automatically provides accurate position and speed data

**Understanding GPS Readings in the App:**
- **SAT**: Number of satellites currently connected (4+ needed for good position fix)
- **HDOP**: Horizontal Dilution of Precision - GPS accuracy indicator
  - **1.0-2.0**: Excellent accuracy (±1-3 meters)
  - **2.0-5.0**: Good accuracy (±3-7 meters) 
  - **5.0+**: Poor accuracy (±10+ meters) - reposition GPS module or use external antenna for better sky view
- **LAT/LON**: Your current position coordinates

## Troubleshooting 🔧

### Dashboard Won't Connect:
- ✅ **iPhone/iPad**: Must use [Bluefy browser](https://apps.apple.com/app/bluefy-web-ble-browser/id1492822055), not Safari
- ✅ **Android/Computer**: Use **Chrome, Edge, or Opera** (not Safari/Firefox)
- ✅ Press BOOT button on ESP32 to activate discovery mode
- ✅ Check that ESP32 LED is on (discovery mode active)
- ✅ Try refreshing the dashboard page

### No Sensor Data:
- ✅ Check all sensor wiring connections
- ✅ Verify 5V power supply is connected to wind sensor. The red LED is on when the device is powered up
- ✅ Make sure sensors are properly mounted (wind sensor needs clear 360° view)

### Wind direction is wrong
- ✅ Make sure the wind sensor is mounted by the arrow pointing to the bow of the boat.

### GPS Not Working:
- ✅ GPS is optional and may not be connected yet
- ✅ Check for clear sky view (GPS needs satellite signals)
- ✅ Wait 1-2 minutes for GPS to acquire satellites

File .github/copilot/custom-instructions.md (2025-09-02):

# Repository custom instructions for GitHub Copilot

## Important Note
**ALWAYS READ THE README.MD FILE FIRST** - It contains comprehensive setup instructions, documentation, and usage guidelines for this project. Use it as your primary reference when working on this project.

## About this project
This is a **full-stack marine IoT project** combining ESP32 firmware development (PlatformIO) with a modern Progressive Web App (PWA) dashboard.

**Project Structure:**
- `firmware/` - ESP32 embedded system (PlatformIO/Arduino framework)
- `web/` - React TypeScript PWA dashboard (Vite build system)
- `docs/` - Comprehensive technical documentation

The project provides sailors on small racing vessels with real-time performance data through a seamless hardware-software integration:

**Data Flow:** ESP32 sensors → BLE → PWA Dashboard → Real-time marine visualization

**Marine Data Points:**
- Speed Over Ground (SOG) via GPS with intelligent noise filtering
- Apparent Wind Speed (AWS) and Direction (AWD) via ultrasonic sensor
- Vessel heel/tilt angle and magnetic heading via 9-axis IMU
- GPS position and satellite status
- BLE connection quality (RSSI)

**Architecture:** ESP32 BLE server using NimBLE-Arduino library, serving standardized JSON marine data to a React TypeScript PWA with Web Bluetooth API integration.

**Key Features:**
- **Full-Stack Integration:** Seamless ESP32 firmware + React PWA development
- **Bluetooth Low Energy (BLE):** NimBLE-Arduino server with Web Bluetooth API client
- **Robust Sensor Handling:** Individual sensors can fail without affecting system operation
- **Standardized Marine JSON API:** Proper maritime terminology (SOG, AWS, AWD, etc.)
- **Real-time Data Streaming:** 1Hz reliable transmission with modern web visualization
- **Power Efficient Design:** Optimized for extended battery operation in marine environments
- **Modern Web Technologies:** React 18 + TypeScript + Vite for fast development and deployment
- **Progressive Web App:** Installable, offline-capable marine dashboard
- **Responsive Design:** Optimized for tablets and smartphones in marine conditions

## Technical Stack

### Firmware (ESP32)
- **Platform:** PlatformIO with Arduino framework
- **Language:** C++11/14 with modern embedded practices
- **Hardware:** ESP32 DevKitC WROOM-32U with external antenna
- **Communication:** NimBLE-Arduino for efficient BLE server implementation
- **Sensors:** BNO080 9-axis IMU, RS485 wind sensor, GPS (future)

### Web Application (PWA)
- **Framework:** React 18 with TypeScript
- **Build System:** Vite for fast development and optimized builds
- **Styling:** Modern CSS with CSS Grid and Flexbox
- **PWA Features:** Service worker, manifest, installable
- **Communication:** Web Bluetooth API for direct ESP32 connection
- **State Management:** React Context API for theme and BLE state

## Hardware Dependencies

**For complete hardware specifications, see [docs/HARDWARE.md](docs/HARDWARE.md)**

### Quick Reference
- **Main Controller:** ESP32 DevKitC WROOM-32U Development Board
- **Sensors:** BNO080 9-axis IMU (tilt, heading, acceleration), RS485 Wind Sensor, GPS (future)
- **Communication:** RS485 to TTL converter for wind sensor
- **Power:** 5V USB or external, ~200mA typical consumption

### Pin Assignments (Current Project)
| Component | ESP32 Pin | Function |
| --- | --- | --- |
| BNO080 IMU Sensor | IO21 (SDA) | I2C Data |
| BNO080 IMU Sensor | IO22 (SCL) | I2C Clock |
| RS485 Wind Sensor | IO32 (RX2) | Serial RX from RS485 converter |
| RS485 Wind Sensor | IO33 (TX2) | Serial TX to RS485 converter |
| RS485 Control | IO14 | DE/RE pin for half-duplex control |
| GPS Module (future) | IO16 (RX) | Serial RX for GPS communication |
| GPS Module (future) | IO17 (TX) | Serial TX for GPS communication |
| Anchor Light | IO25 | PWM LED control (masthead) |
| Discovery Button | IO0 | Built-in BOOT button |
| Status LED | IO2 | Built-in LED |

## Software Architecture Reference

The software architecture has been migrated from WiFi Access Point to BLE connectivity:

### Current Architecture (BLE-based)
- **ESP32:** BLE server using NimBLE-Arduino library
- **Connectivity:** Bluetooth Low Energy with multi-client support
- **Data Format:** Standardized JSON with marine terminology
- **Web App:** Externally hosted (GitHub Pages/Netlify) over HTTPS
- **Client Connection:** Web Bluetooth API for direct ESP32 connection

### Communication Flow
1. **GPS Module** → UART (GPIO 16/17) → ESP32 → JSON over BLE
2. **BNO080 IMU Sensor** → I2C (GPIO 21/22) → ESP32 → JSON over BLE
3. **Wind Sensor** → RS485 → RS485 Transceiver → UART (GPIO 25/26) → ESP32 → JSON over BLE

### BLE Service Configuration
- **Service UUID:** 12345678-1234-1234-1234-123456789abc
- **Characteristic UUID:** 87654321-4321-4321-4321-cba987654321
- **Data Rate:** 1Hz (1000ms intervals)
- **Data Format:** JSON string with standardized marine fields

### JSON API Fields
- **Always Present:** SOG, COG, lat, lon, satellites, hdop, rssi
- **Conditional:** AWS, AWD (wind sensor), heel (BNO080 IMU sensor)
- **Marine Standards:** Uses proper marine terminology and units

### Error Handling
- **Sensor Failures:** Individual sensors can fail without affecting system
- **Missing Sensors:** Detected at startup, graceful degradation
- **I2C/RS485 Errors:** Timeouts prevent blocking, warnings logged periodically
- **BLE Reliability:** Data transmission continues regardless of sensor status

### Power Management
- **BLE Efficiency:** ~50% less power than WiFi approach
- **NimBLE Library:** Optimized for low power consumption
- **Sensor Management:** Failed sensors don't consume retry power

## Development Workflows

### Firmware Development (firmware/)
- **Build:** Use VS Code PlatformIO tasks or `pio run` in root directory
- **Upload:** Use task buttons or `pio run --target upload`
- **Monitor:** Built-in serial monitor for debugging
- **Structure:** Standard PlatformIO layout with src/, lib/, include/ directories

### Web Development (web/)
- **Development:** `npm run dev` for Vite dev server with hot reload
- **Build:** `npm run build` for production deployment
- **Preview:** `npm run preview` to test production build locally
- **Structure:** Modern React project with components/, hooks/, context/, utils/

### Unified Development
- **Root Tasks:** VS Code tasks available for both firmware and web builds
- **Documentation:** Centralized in docs/ with markdown files
- **Version Control:** Single repository with clear separation of concerns
- **Testing:** BLE communication testing between firmware and web components

## Coding Preferences

### Firmware (C++)
- Prefer C++ style with modern C++11/14 features
- Follow PlatformIO project structure conventions
- Use descriptive variable names and clear commenting
- Implement robust error handling for sensor failures
- Use appropriate low-power techniques for battery efficiency
- Prefer non-blocking code to maintain system responsiveness
- **BLE Focus:** Use NimBLE-Arduino for efficient BLE communication
- **Marine Standards:** Use proper marine terminology in JSON API (SOG, AWS, AWD, etc.)
- **Sensor Robustness:** Handle missing/failed sensors gracefully

### Web Application (TypeScript/React)
- Follow React 18 best practices with functional components and hooks
- Use TypeScript for type safety and better developer experience
- Implement proper error boundaries and loading states
- Use CSS custom properties for theming (light/dark mode)
- Follow PWA best practices for offline functionality
- **Web Bluetooth:** Handle connection states and errors gracefully
- **Marine UX:** Design for readability in bright sunlight conditions
- **Responsive Design:** Optimize for marine tablet/smartphone usage

## Problem-Solving Approach

### Firmware Development
When generating embedded code for this project, consider:
- Power efficiency for battery-operated marine devices
- Memory constraints of ESP32 and real-time performance requirements
- Error handling for sensor failures without blocking main loop
- Environmental challenges of marine applications (vibration, moisture, temperature)
- BLE connectivity optimization for low-latency, multi-client communication
- Marine environment considerations (power consumption, reliability)

### Web Development
When working on the PWA, consider:
- Marine UX requirements (sunlight readability, touch-friendly interfaces)
- Web Bluetooth API limitations and browser compatibility
- Offline functionality and data persistence
- Responsive design for various screen sizes in marine environments
- Performance optimization for lower-end mobile devices
- Progressive enhancement for different device capabilities

### Full-Stack Integration
- Maintain consistent marine terminology between firmware JSON API and web UI
- Handle BLE connection states gracefully on both ends
- Ensure data validation and error handling across the entire stack
- Document API changes that affect both firmware and web components
- Consider power management implications of BLE communication patterns
- **Prefer VS Code tasks over CLI commands** for unified development workflow
- **Update documentation** when making significant changes to maintain accuracy

## Project Context

This is a **professional marine IoT solution** that requires careful consideration of:

**Hardware Constraints:**
- ESP32 memory limitations and real-time performance requirements
- Battery power efficiency for extended operation in marine environments
- Sensor reliability and environmental challenges of marine conditions

**Software Architecture:**
- **Firmware:** NimBLE-Arduino BLE server with standardized marine JSON API
- **Web App:** React TypeScript PWA with Web Bluetooth integration
- **Communication:** Standardized JSON with conditional field presence based on sensor availability
- **Error Resilience:** Robust error handling without system interruption on both firmware and web sides
- **Multi-Client Support:** Simultaneous BLE connections to multiple devices/browsers

**Current Status:**
- **Unified Repository:** Both firmware and web app in single repository with clear separation
- **Modern Development Stack:** PlatformIO + Vite for fast development cycles
- **Standardized Marine API:** Proper maritime terminology and units throughout
- **Production Ready:** Robust error handling, power optimization, and comprehensive documentation
- **Cross-Platform PWA:** Works on desktop, tablet, and mobile devices

**Key Libraries & Dependencies:**

*Firmware:*
- NimBLE-Arduino for BLE communication
- ArduinoJson for JSON serialization
- SparkFun BNO080 library for 9-axis IMU sensor
- TinyGPS++ for GPS parsing (future integration)

*Web Application:*
- React 18 with TypeScript for UI framework
- Vite for build tooling and development server
- Web Bluetooth API for ESP32 communication
- CSS custom properties for theming system

Refer to the README.md file for comprehensive implementation details, setup instructions, and development workflows for both firmware and web components.

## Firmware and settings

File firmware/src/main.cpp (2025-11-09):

#include <Arduino.h>
#include <ArduinoJson.h>
#include <Preferences.h>
#include <vector>
#include <TinyGPS++.h>
#include <Wire.h>
#include <SparkFun_BNO080_Arduino_Library.h>
#include <NimBLEDevice.h>
#include <ModbusMaster.h>
#include <Update.h>
#include <esp_ota_ops.h>

// Firmware version
#define FIRMWARE_VERSION "0.0.26"

// Simple base64 decoding table
const char base64_chars[] = "ABCDEFGHIJKLMNOPQRSTUVWXYZabcdefghijklmnopqrstuvwxyz0123456789+/";

// Base64 decode function
int base64_decode(const char* input, uint8_t* output) {
  int input_len = strlen(input);
  if (input_len % 4 != 0) return -1;
  
  int output_len = input_len / 4 * 3;
  if (input[input_len - 1] == '=') output_len--;
  if (input[input_len - 2] == '=') output_len--;
  
  int i, j;
  uint32_t sextet_a, sextet_b, sextet_c, sextet_d;
  uint32_t triple;
  
  for (i = 0, j = 0; i < input_len;) {
    sextet_a = input[i] == '=' ? 0 & i++ : strchr(base64_chars, input[i++]) - base64_chars;
    sextet_b = input[i] == '=' ? 0 & i++ : strchr(base64_chars, input[i++]) - base64_chars;
    sextet_c = input[i] == '=' ? 0 & i++ : strchr(base64_chars, input[i++]) - base64_chars;
    sextet_d = input[i] == '=' ? 0 & i++ : strchr(base64_chars, input[i++]) - base64_chars;
    
    triple = (sextet_a << 3 * 6) + (sextet_b << 2 * 6) + (sextet_c << 1 * 6) + (sextet_d << 0 * 6);
    
    if (j < output_len) output[j++] = (triple >> 2 * 8) & 0xFF;
    if (j < output_len) output[j++] = (triple >> 1 * 8) & 0xFF;
    if (j < output_len) output[j++] = (triple >> 0 * 8) & 0xFF;
  }
  
  return output_len;
}

// Debug flags - uncomment for verbose output
// #define DEBUG_BLE_DATA
#define DEBUG_WIND_SENSOR
// #define DEBUG_GPS
#define DEBUG_BNO080

// Persistent storage for settings
Preferences preferences;
float heelAngleDelta = 0.0f;
float compassOffsetDelta = 0.0f; // Compass calibration offset in degrees
int deadWindAngle = 40; // default
float refreshRateSeconds = 1.0f; // Default 1.0 second refresh rate
bool otaInProgress = false; // Flag to pause sensor data during firmware updates
unsigned long otaStartTime = 0; // Track when OTA started for timeout
unsigned long lastOTAActivity = 0; // Track last OTA activity for debugging
const unsigned long OTA_TIMEOUT_MS = 60000; // 1 minute timeout for OTA updates  
const unsigned long OTA_ACTIVITY_TIMEOUT_MS = 15000; // 15 second activity timeout
const unsigned long OTA_STATUS_INTERVAL_MS = 5000; // Status check every 5 seconds

// BLE Configuration
#define SERVICE_UUID        "12345678-1234-1234-1234-123456789abc"
#define SENSOR_DATA_UUID    "87654321-4321-4321-4321-cba987654321"
#define COMMAND_UUID        "11111111-2222-3333-4444-555555555555"

NimBLEServer* pServer = NULL;
NimBLECharacteristic* pSensorDataCharacteristic = NULL;
NimBLECharacteristic* pCommandCharacteristic = NULL;
bool deviceConnected = false;
bool oldDeviceConnected = false;
int bleRSSI = 0; // BLE signal strength
int bleRSSIFiltered = 0; // Smoothed RSSI value for display
uint16_t connectedDeviceCount = 0; // Track number of connected devices
bool bleSending = false; // Prevent concurrent BLE transmissions

// BLE-based OTA update variables
static bool bleOTAActive = false;
static size_t otaWritten = 0;
static size_t otaSize = 0;

// BNO080 IMU Sensor (I2C)
#define BNO080_SDA 21
#define BNO080_SCL 22
BNO080 imu;
bool imuAvailable = false; // Track if IMU is working

// RS485 Wind Sensor Configuration
#define RS485_DE 14
#define RS485_RX 32
#define RS485_TX 33
#define RS485_UART 2

// GPS Module Configuration (using UART1)
#define GPS_RX 17
#define GPS_TX 16
#define GPS_UART 1

// Discovery Mode Configuration
#define DISCOVERY_BUTTON_PIN 0     // GPIO0 (BOOT button on ESP32 dev boards)
#define DISCOVERY_LED_PIN 2        // GPIO2 for discovery status LED (built-in LED)
#define DISCOVERY_TIMEOUT_MS (5 * 60 * 1000)  // 5 minutes timeout

bool discoveryModeActive = false;
unsigned long discoveryModeStartTime = 0;
bool lastButtonState = HIGH;
unsigned long lastButtonDebounceTime = 0;
const unsigned long debounceDelay = 50;
bool buttonProcessed = false;

// RS485 Wind Sensor
HardwareSerial rs485(RS485_UART);
ModbusMaster windSensor;

// GPS Module
HardwareSerial gpsSerial(GPS_UART);
TinyGPSPlus gps;

// Regatta start line data structure
struct RegattaData {
  bool hasStartLine;         // True if both port and starboard positions are set
  double portLat;           // Port end GPS latitude
  double portLon;           // Port end GPS longitude
  double starboardLat;      // Starboard end GPS latitude  
  double starboardLon;      // Starboard end GPS longitude
  float distanceToLine;     // Current distance to start line in meters
};

// Regatta data
RegattaData regattaData = {false, 0.0, 0.0, 0.0, 0.0, -1.0};

// Regatta Functions (prototypes)
float haversineDistance(double lat1, double lon1, double lat2, double lon2);
float distanceToLine(double px, double py, double x1, double y1, double x2, double y2);
void calculateRegattaData();

// Function prototypes (declared early for use in callbacks)
bool safeBLESend(const String& data, bool isCommand = false);
void setupBLE();
void restartBLE();
void setupBLEServer();
void preTransmission();
void postTransmission();
void generateRandomBLEAddress();
void resetBLEForNewName(const String& newName);
void handleDiscoveryButton();
void startDiscoveryMode();
void stopDiscoveryMode();
void updateDiscoveryStatus();
void updateRefreshRate();

// Safe BLE transmission function to prevent data corruption
bool safeBLESend(const String& data, bool isCommand) {
  Serial.printf("[BLE DEBUG] Attempting to send %d chars, command=%s\n", 
               data.length(), isCommand ? "true" : "false");
  
  // Check if we have a valid connection and characteristic
  if (!pServer || pServer->getConnectedCount() == 0 || !pSensorDataCharacteristic) {
    Serial.println("[BLE DEBUG] FAILED: No server, connection, or characteristic");
    return false;
  }
  
  Serial.printf("[BLE DEBUG] Connected devices: %d\n", pServer->getConnectedCount());
  
  // Wait for any ongoing transmission to complete (max 100ms timeout)
  unsigned long startTime = millis();
  while (bleSending && (millis() - startTime) < 100) {
    delay(1);
  }
  
  // If still sending after timeout, skip this transmission
  if (bleSending) {
    Serial.println("[BLE DEBUG] FAILED: Transmission timeout, skipping...");
    return false;
  }
  
  // Set sending flag
  bleSending = true;
  Serial.println("[BLE DEBUG] Sending flag set, starting transmission...");
  
  try {
    // Convert string to byte array to avoid encoding issues
    std::vector<uint8_t> dataBytes(data.begin(), data.end());
    Serial.printf("[BLE DEBUG] Converted to %d bytes\n", dataBytes.size());
    
    pSensorDataCharacteristic->setValue(dataBytes);
    Serial.println("[BLE DEBUG] Characteristic value set");
    
    pSensorDataCharacteristic->notify();
    Serial.println("[BLE DEBUG] Notify called");
    
    // Small delay to ensure transmission completes
    delay(isCommand ? 10 : 5);
    Serial.printf("[BLE DEBUG] Delay completed (%d ms)\n", isCommand ? 10 : 5);
    
    bleSending = false;
    Serial.println("[BLE DEBUG] SUCCESS: Transmission completed");
    return true;
  } catch (...) {
    bleSending = false;
    Serial.println("[BLE DEBUG] FAILED: Exception during transmission");
    return false;
  }
}

// BLE Server Callbacks
class MyServerCallbacks: public NimBLEServerCallbacks {
    void onConnect(NimBLEServer* pServer) {
      connectedDeviceCount++;
      deviceConnected = true;
      Serial.printf("BLE Client connected (total: %d)\n", connectedDeviceCount);
      
      // Send firmware version after connection
      delay(1000); // Give client time to set up characteristics
      if (pSensorDataCharacteristic) {
        DynamicJsonDocument doc(128);
        doc["type"] = "firmware_version";
        doc["version"] = FIRMWARE_VERSION;
        String versionData;
        serializeJson(doc, versionData);
        
        if (safeBLESend(versionData, true)) {
          Serial.printf("Sent firmware version on connect: %s\n", FIRMWARE_VERSION);
        } else {
          Serial.println("Failed to send firmware version on connect");
        }
      }
      
      // Continue advertising if we haven't reached max connections AND discovery mode is active
      if (connectedDeviceCount < CONFIG_BT_NIMBLE_MAX_CONNECTIONS && discoveryModeActive) {
        delay(100); // Small delay before restarting advertising
        NimBLEDevice::startAdvertising();
        Serial.printf("Continuing advertising for additional connections... (%d/%d connected)\n", 
                     connectedDeviceCount, CONFIG_BT_NIMBLE_MAX_CONNECTIONS);
      } else {
        if (connectedDeviceCount >= CONFIG_BT_NIMBLE_MAX_CONNECTIONS) {
          Serial.printf("Maximum connections reached (%d/%d)\n", 
                       connectedDeviceCount, CONFIG_BT_NIMBLE_MAX_CONNECTIONS);
        } else {
          Serial.println("Discovery mode not active, stopping advertising for new connections");
        }
      }
    };

    void onDisconnect(NimBLEServer* pServer) {
      connectedDeviceCount--;
      if (connectedDeviceCount == 0) {
        deviceConnected = false;
        bleRSSI = 0; // Reset RSSI when all devices disconnected
      }
      Serial.printf("BLE Client disconnected (remaining: %d/%d)\n", 
                   connectedDeviceCount, CONFIG_BT_NIMBLE_MAX_CONNECTIONS);
      
      // Restart advertising when a device disconnects if discovery mode is active
      delay(500);
      if (!NimBLEDevice::getAdvertising()->isAdvertising() && discoveryModeActive && connectedDeviceCount < CONFIG_BT_NIMBLE_MAX_CONNECTIONS) {
        NimBLEDevice::startAdvertising();
        Serial.println("Restarting advertising after disconnection (discovery mode active)...");
      } else if (!discoveryModeActive) {
        Serial.println("Discovery mode not active, not restarting advertising");
      }
    }
};
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
void loop() {
  // Handle discovery button and mode
  handleDiscoveryButton();
  updateDiscoveryStatus();
  
  // Handle OTA progress LED blinking using official component
  if (bleOTAActive) {
    unsigned long currentTime = millis();
    
    // Periodic status reporting (every 5 seconds)
    static unsigned long lastStatusReport = 0;
    if (currentTime - lastStatusReport > 5000) {
      unsigned long elapsedMinutes = (currentTime - otaStartTime) / 60000;
      Serial.printf("[BLE OTA] Status: Active for %lu ms (%lu minutes) using official Espressif component\n", 
                   currentTime - otaStartTime, elapsedMinutes);
      
      // Warn when approaching timeout (at 50 minutes)
      if (elapsedMinutes >= 50) {
        Serial.printf("[BLE OTA] WARNING: Approaching timeout in %lu minutes\n", 60 - elapsedMinutes);
      }
      
      lastStatusReport = currentTime;
    }
    
    // Check for total OTA timeout (60 minutes - allow for very large firmware and slow BLE)
    if (currentTime - otaStartTime > 3600000) { // 60 minutes
      Serial.printf("[BLE OTA] Total timeout after %lu ms (%lu minutes). Component will handle cleanup.\n", 
                   currentTime - otaStartTime, (currentTime - otaStartTime) / 60000);
      bleOTAActive = false;
      otaStartTime = 0;
      
      // Turn off LED and resume normal operation
      digitalWrite(DISCOVERY_LED_PIN, LOW);
      Serial.println("[BLE OTA] Timeout recovery complete - resuming sensor data transmission");
      return;
    }
    
    static unsigned long lastOTABlink = 0;
    if (millis() - lastOTABlink >= 100) { // Very fast blink every 100ms
      digitalWrite(DISCOVERY_LED_PIN, !digitalRead(DISCOVERY_LED_PIN));
      lastOTABlink = millis();
    }
    delay(10); // Small delay to prevent tight loop, but keep responsive
    return;
  }
  
  // Check if it's time to update data
  if (millis() >= nextUpdate) {
    // Read sensor data
    readSensors();
    
    // Calculate regatta data if start line is set
    calculateRegattaData();
    
    // Update BLE RSSI if connected
    updateBLERSSI();
    
    // Update BLE clients with sensor data
    updateBLEData();
    
    // Set next update time
    nextUpdate = millis() + refreshRate;
    
    // Print concise status summary every 5 seconds
    static unsigned long lastStatusTime = 0;
    if (millis() - lastStatusTime > 5000) {
      Serial.print("Status: ");
      if (deviceConnected) {
        Serial.printf("BLE✓(%d) ", connectedDeviceCount);
        if (bleRSSIFiltered != 0) Serial.printf("RSSI:%ddBm ", bleRSSIFiltered);
      }
      if (discoveryModeActive) {
        unsigned long remaining = (DISCOVERY_TIMEOUT_MS - (millis() - discoveryModeStartTime)) / 1000;
        Serial.printf("Discovery:%lus ", remaining);
      }
      if (!isnan(currentData.speed) && currentData.speed > 0) 
        Serial.printf("Spd:%.1fkt ", currentData.speed);
      if (!isnan(currentData.windSpeed)) 
        Serial.printf("Wind:%.1fkt AWA:%d° ", currentData.windSpeed, currentData.windAngle);
      if (!isnan(currentData.tilt)) 
        Serial.printf("Tilt:%.1f° ", currentData.tilt);
      if (currentData.HDM >= 0 && currentData.HDM <= 359) 
        Serial.printf("Hdm:%d° ", currentData.HDM);
      
      // GPS status - only show satellite count if we have actual GPS data
      if (gps.charsProcessed() > 10) {
        // We're receiving GPS data
        if (isGPSDataValid()) {
          Serial.printf("GPS:%dsat✓ ", gps.satellites.value());
        } else if (gps.satellites.isValid()) {
          Serial.printf("GPS:%dsat(no fix) ", gps.satellites.value());
        } else {
          Serial.print("GPS:parsing ");
        }
      } else {
        // No GPS data being received
        Serial.print("GPS:no data ");
      }
      
      Serial.println();
      lastStatusTime = millis();
    }
  }
}

// GPS track-based filtering variables
const int GPS_TRACK_BUFFER_SIZE = 10;  // Track last 10 positions
struct GPSPoint {
  double lat;
  double lon;
  float speed;
  unsigned long timestamp;
  bool valid;
};

// Accelerometer-based movement detection variables
const int ACCEL_BUFFER_SIZE = 8;  // Track last 8 acceleration readings
struct AccelPoint {
  float x, y, z;
  float magnitude;
  unsigned long timestamp;
  bool valid;
};

static GPSPoint gpsTrackBuffer[GPS_TRACK_BUFFER_SIZE];
static int gpsTrackIndex = 0;
static bool gpsTrackBufferFull = false;
static float lastValidSpeed = 0.0;

static AccelPoint accelBuffer[ACCEL_BUFFER_SIZE];
static int accelIndex = 0;
static bool accelBufferFull = false;

// Calculate distance between two GPS points in meters
float calculateDistance(double lat1, double lon1, double lat2, double lon2) {
  const float R = 6371000; // Earth's radius in meters
  float dLat = (lat2 - lat1) * PI / 180.0;
  float dLon = (lon2 - lon1) * PI / 180.0;
  float a = sin(dLat/2) * sin(dLat/2) +
            cos(lat1 * PI / 180.0) * cos(lat2 * PI / 180.0) *
            sin(dLon/2) * sin(dLon/2);
  float c = 2 * atan2(sqrt(a), sqrt(1-a));
  return R * c;
}

// Calculate bearing between two GPS points in degrees
float calculateBearing(double lat1, double lon1, double lat2, double lon2) {
  float dLon = (lon2 - lon1) * PI / 180.0;
  float y = sin(dLon) * cos(lat2 * PI / 180.0);
  float x = cos(lat1 * PI / 180.0) * sin(lat2 * PI / 180.0) -
            sin(lat1 * PI / 180.0) * cos(lat2 * PI / 180.0) * cos(dLon);
  float bearing = atan2(y, x) * 180.0 / PI;
  return fmod(bearing + 360.0, 360.0);
}

// Transform accelerometer data from device coordinates to vessel coordinates using calibration
// This uses the level calibration (heelAngleDelta) and compass calibration (compassOffsetDelta)
// to create a rotation matrix that transforms device coordinates to vessel coordinates
void transformAccelerometerToVessel(float deviceX, float deviceY, float deviceZ, 
                                   float &vesselForward, float &vesselStarboard, float &vesselUp) {
  
  // For now, we'll assume the device coordinate system aligns with vessel coordinates
  // after level and compass calibration. This is a simplified approach.
  // In a full implementation, we'd need to determine the device mounting orientation
  // and create proper rotation matrices.
  
  // Simplified mapping (this assumes device X=forward, Y=starboard, Z=up)
  // This will need to be enhanced based on actual device mounting
  vesselForward = deviceX;    // Forward/aft acceleration
  vesselStarboard = deviceY;  // Port/starboard acceleration  
  vesselUp = deviceZ;         // Up/down acceleration
  
  // TODO: Apply proper rotation matrix transformation using heelAngleDelta and compassOffsetDelta
  // This would involve creating a 3D rotation matrix that accounts for:
  // 1. Device mounting orientation relative to vessel
  // 2. Current heel angle compensation
  // 3. Compass heading compensation
}

// Get forward acceleration (positive = accelerating forward)
float getForwardAcceleration(float accelX, float accelY, float accelZ) {
  float forward, starboard, up;
  transformAccelerometerToVessel(accelX, accelY, accelZ, forward, starboard, up);
  return forward;
}

// Get starboard acceleration (positive = accelerating to starboard/right)
float getStarboardAcceleration(float accelX, float accelY, float accelZ) {
  float forward, starboard, up;
  transformAccelerometerToVessel(accelX, accelY, accelZ, forward, starboard, up);
  return starboard;
}

// Get up acceleration (positive = accelerating upward)
float getUpAcceleration(float accelX, float accelY, float accelZ) {
  float forward, starboard, up;
  transformAccelerometerToVessel(accelX, accelY, accelZ, forward, starboard, up);
  return up;
}

// Store accelerometer reading for movement analysis
void storeAccelReading(float accelX, float accelY, float accelZ) {
  if (!imuAvailable) return;
  
  AccelPoint point;
  point.x = accelX;
  point.y = accelY;
  point.z = accelZ;
  point.magnitude = sqrt(accelX * accelX + accelY * accelY + accelZ * accelZ);
  point.timestamp = millis();
  point.valid = true;
  
  accelBuffer[accelIndex] = point;
  accelIndex = (accelIndex + 1) % ACCEL_BUFFER_SIZE;
  
  if (!accelBufferFull && accelIndex == 0) {
    accelBufferFull = true;
  }
}
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

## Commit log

2025-06-03 LED doesn't seem to work, removing for now
    [main.cpp]
2025-07-07 real rssi, multiple devices support
2025-07-07 Fixing the AWA of -1
    [main.cpp]
2025-07-07 Improved SOG noise filtering
    [main.cpp]
2025-07-16 Different SOG noise detection
    [main.cpp]
2025-08-10 Device name
2025-08-11 Device name change now works - avoiding caching by random address
    [main.cpp]
2025-08-12 Device name configuration
2025-08-12 Using the accelerometer for SOG noise reduction
    [main.cpp]
2025-08-17 Implement firmware update functionality via BLE
    Phase 1 - Infrastructure and UI Implementation:
    - Add firmware version tracking to BLE context
    - Create GitHub API utilities for release management
    - Implement BLE firmware updater with chunked transfer
    - Add FirmwareUpdateCard component with progress tracking
    - Integrate firmware update into Settings menu
    Features:
    - Automatic firmware version detection on BLE connection
    - GitHub release checking with semantic version comparison
    - Progress tracking during firmware updates
    - Safety warnings and confirmation dialogs
    - ESP32 OTA update support with proper error handling
    Technical Implementation:
    - BLE command protocol for firmware operations
    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
    [main.cpp]
2025-08-18 Switching back to to main after release
2025-08-18 Level calibration update (wording)
2025-08-18 Compass calibration
2025-08-18 Calculating accelerometer calibration based on the other 6 axes that will be calibrated manually
2025-08-29 Fixing multiple BLE connections
    [main.cpp]
2025-09-01 Updating the actual board
2025-09-01 Circle button fix
2025-09-15 Swapping the GPS pins as the PCB got it wrong
    [main.cpp]
2025-09-26 Readable update button
2025-10-04 Multiple BLE devices fix
    [main.cpp]
2025-10-06 Better button press
2025-10-14 Gerber files added
    [Drill_NPTH_Through.DRL, Drill_PTH_Through.DRL, Drill_PTH_Through_Via.DRL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]
2025-11-07 More OTA partition time to switch
2025-11-09 Aborting previous upgrade in an edge case
2025-11-21 fix: use useRef for firmware updater to prevent race conditions
    Convert currentFirmwareUpdater from let variable to useRef to ensure
    the reference persists across React component re-renders. This fixes
    race conditions where acknowledgments could be lost due to the
    variable being reset during component lifecycle updates.
    - Import useRef from React
    - Change currentFirmwareUpdater to currentFirmwareUpdaterRef.current
    - Ensures reliable acknowledgment forwarding during BLE firmware updates
2025-11-21 Enhancing gps antenna docs
2025-11-21 Linking the live PCB design
